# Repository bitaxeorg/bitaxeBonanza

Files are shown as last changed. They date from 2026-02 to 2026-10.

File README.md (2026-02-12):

bitaxeBonanza quad Intel BZM2 ASIC miner.

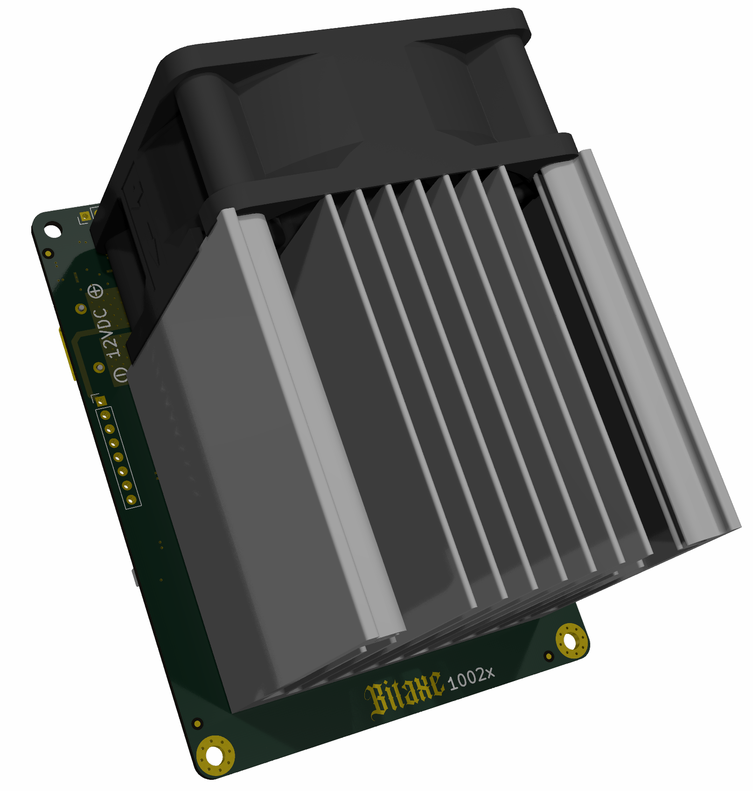
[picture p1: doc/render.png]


It is still an untested prototype! Don't build this expecting it to work out of the box. Do build it if you want to hack on some rad stuff.

- [Open Hardware License](LICENSE); Real Open Source.
	- [KiCAD](https://kicad.org) design files. 
- Four Intel BZM2 ASICs, powered in series.
	- Each BZM2 is [nominally](doc/specs.md) 0.7V with approx 350 GH/s @ 1.15 GHz hash frequency.
	- On chip digital temperature and voltage sensors
	- ntime rolling
- 11-13V XT30 input voltage
- TPS546D24S single-phase voltage regulator tuned for 2.8V output @ 20A
	- The voltage regulator backside power plane is exposed to hopefully thermally bond it with the main heatsink. 
- New fan control strategy (no more EMC2101)
- ESP32S3 for [esp-miner](https://github.com/bitaxeorg/esp-miner) support.
- 9-bit serial ASIC support via RP2040
    - Preliminary support with the [bitaxe-raw-pico](https://github.com/bitaxeorg/bitaxe-raw/tree/pico) firmware.
- Gerbers _not_ provided to discourage side hacks and AliEx slop. HMU if you need help generating gerbers with KiCad.

©️ [bitaxeorg](https://bitaxe.org)

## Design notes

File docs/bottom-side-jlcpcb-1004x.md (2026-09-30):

# Bottom-side JLCPCB parts — bitaxeBonanza 1004x

Catalog review: 2026-09-29. Source: saved `bitaxeBonanza.kicad_pcb` B.Cu position export joined to the schematic BOM, with the bitaxeProto-1103x BOM used for existing choices. Stock changes; recheck before placing an order.

- 209 bottom-side footprints: 180 schematic BOM parts in 56 original PARTNO groups, plus 29 test points, fiducials, mounting holes, and a net tie outside the assembly BOM.
- All 180 BOM positions have a selected JLCPCB/LCSC catalog code. These are candidate assembly selections, not an indication that all parts can be ordered today.
- 12 × D1–D12 use Preferred C7502722 (BAS516), with 33,674 available and the existing SOD-523 footprint. L1 now uses stocked Extended C3224581 (Bourns SRP1245A-1R2M).
- Equivalents are labeled separately from exact MPNs. Basic was selected where value, package, voltage, dielectric/tolerance or resistor rating agree. The 10 µF 25 V 0603 capacitor retains its ±10% exact part because the proto Basic choice is ±20%. Y1 uses the requested Proto Basic crystal, whose stability is ±20 ppm versus the original ±10 ppm.
- The saved schematic BOM has the selected `LCSC` code on all 180 bottom-side positions, including the manually updated reused sheets.

## Parts needing attention

| References | Selection | Finding |
| --- | --- | --- |
| D1–D12 | [C7502722](https://www.lcsc.com/product-detail/C7502722.html) | Preferred BAS516, 33,674 available; same SOD-523 footprint. It is rated 75 V versus the original 80 V. |
| L1 | [C3224581](https://jlcpcb.com/partdetail/BOURNS-SRP1245A1R2M/C3224581) | Bourns SRP1245A-1R2M, 65 available at the latest live check. The saved schematic and PCB use its land pattern; see verification below. |
| Q1 | [C7420339](https://www.lcsc.com/product-detail/C7420339.html) | Requested Proto generic BSS138 in SOT-23; this is an alternative to the original BSS138K-13 PARTNO. |
| Y2 | [C5137267](https://www.lcsc.com/product-detail/C5137267.html) | Exact 50 MHz oscillator, 10 available. This limits a multiple-board order. |
| D13 | [C24672](https://www.lcsc.com/product-detail/C24672.html) | Proto 3.3 V SOD-123 zener. Original DDZ9684-7 exact C165455 has 3 available. |
| Y1 | [C9002](https://www.lcsc.com/product-detail/C9002.html) | Requested Proto Basic 12 MHz, 20 pF, SMD3225-4P crystal; ±20 ppm stability versus the original ±10 ppm. |
| J1 | [C431092](https://www.lcsc.com/product-detail/C431092.html) | Proto XT30PW-M30.G.Y variant; confirm pin/tail geometry of the custom footprint. |

## D1–D12 replacement review

These diodes connect adjacent ASIC logic signals (TRIP, TX, RESET, and RX) with 1 kΩ resistors to the local 1.2 V rail or ground. The exported netlist indicates a low-voltage interface; the 75 V rating of BAS516 is ample for that use, although it is below the original diode's 80 V rating. The selected [BAS516 datasheet](https://wmsc.lcsc.com/wmsc/upload/file/pdf/v2/lcsc/2311171118_hongjiacheng-BAS516_C7502722.pdf) and [original DLLFSD01T datasheet](https://www.diodes.com/datasheet/download/DLLFSD01T.pdf) give:

| Property | Original DLLFSD01T-7 | Preferred BAS516 C7502722 | Preferred 1SS400 C7502721 |
| --- | --- | --- | --- |
| Package | SOD-523 | SOD-523 | SOD-523 |
| Reverse rating | 80 V | 75 V | 80 V |
| Forward voltage at 1 mA, max | 0.700 V | 0.715 V | Not specified |
| Capacitance at 0 V, max | 2.5 pF | 1.0 pF | 3.0 pF |
| Reverse recovery, max | 4 ns | 4 ns | 4 ns |
| Reverse leakage, max | 10 nA at 5 V; 0.2 µA at 80 V | 30 nA at 25 V; 1 µA at 75 V | 0.1 µA at 80 V |

The leakage figures use different test voltages and should not be compared as if measured under one condition. BAS516 has a specified low-current forward voltage and lower capacitance, which makes it the better fit for these logic shifters. [1SS400 C7502721](https://www.lcsc.com/product-detail/C7502721.html) is a same-footprint Preferred backup. The only Basic SOD-323 switching diode found, [1N4148WS C2128](https://www.lcsc.com/product-detail/C2128.html), needs a larger footprint and has a 1 µA leakage specification at 75 V. No Basic SOD-523 switching diode was listed in the catalog search.

The exact DLLFSD01T-7 is [C460049](https://www.lcsc.com/product-detail/C460049.html), with only 5 available for the 12 positions at the time of this review.

The existing `bitaxe:D_SOD-523` pads are 0.6 × 0.7 mm with 1.4 mm center spacing, within the BAS516 datasheet's suggested 0.55–0.65 × 0.65–0.75 mm pads and 1.37–1.47 mm spacing. No PCB footprint change is needed. Verify logic levels and edge timing on the first assembled board.

KiCad's saved schematic now exports BAS516 as the Value and PARTNO for D1–D12, with the new manufacturer and datasheet. The manually added `LCSC=C7502722` is present on all twelve exported BOM positions. The saved PCB footprint Values still show DLLFSD01T-7 because the PCB editor IPC endpoint did not accept Konnect's edit call.

## L1 replacement research

The saved [WEBENCH design report](../WebBench/WBDesign-1004x.pdf) is for 11–13 V input, 2.8 V at 20 A output, and 325 kHz switching. It calculates 5.738 A peak-to-peak inductor ripple and 22.869 A peak switch current. Current through L1 is therefore about 20.07 A RMS at that reported operating point. The report uses TPS546D24A, while the saved KiCad BOM names TPS546D24SRVFR for U2. The user has verified that TPS546D24S is a drop-in replacement for TPS546D24A; the WEBENCH values remain a reported operating point rather than a measurement of this board. The original Coilcraft XAL1060-122MEC is 1.2 µH, 2.5 mΩ typical DCR, 43 A saturation, and 17.9/26.3 A for a 20/40 °C rise [per Coilcraft](https://www.coilcraft.com/en-us/products/power/shielded-inductors/molded-inductor/xal/xal1060/xal1060-122/).

JLCPCB stock was checked live on 2026-09-29; all viable high-current choices found are **Extended** parts. The cataloged stock is an availability snapshot, not a reservation. The former L1 code C3911742 was out of stock; the selected C3224581 showed 65 in stock.

| Candidate | LCSC | µH | DCR typ/max | Irms | Isat | Body | Live stock | Assessment |
| --- | --- | ---: | ---: | ---: | ---: | --- | ---: | --- |
| [Bourns SRP1245A-1R2M](https://www.bourns.com/docs/product-datasheets/srp1245a.pdf) | [C3224581](https://jlcpcb.com/partdetail/BOURNS-SRP1245A1R2M/C3224581) | 1.2 | 2.5/3.0 mΩ | 28 A | 49 A | 13.5 × 12.5 × 4.8 mm | 65 | Selected and placed in KiCad. |
| Vishay IHLP5050FDER1R5M01, in WEBENCH list | [C1336173](https://www.lcsc.com/product-detail/C1336173.html) | 1.5 | 2.5 mΩ catalog value | 27 A | 45 A | 13.2 × 12.9 × 6.5 mm | 233 | Electrically plausible; WEBENCH accepts 1.5 µH. New footprint and height check needed. |
| [Tai-Tech TMPC1265HP-1R5MG-D](https://www.tai-tech.com.tw/tmpc1265hp) | [C357270](https://www.lcsc.com/product-detail/C357270.html) | 1.5 | 2.5/3.0 mΩ | 27 A | 45 A | 13.5 × 12.5 × 6.2 mm | 385 | More stocked 1.5 µH option; new footprint and compensation check needed. |
| Coilank APS1060M1R2F | [C49261245](https://www.lcsc.com/product-detail/C49261245.html) | 1.2 | 2.64 mΩ catalog value | 26.5 A | 45 A | 11.9 × 11 mm | 82 | Closest body size; manufacturer land pattern and current definitions still need verification. |

L1 now uses `bitaxe:SRP1245A-180M_BRN` in the schematic and on the bottom PCB. Although the footprint's library name contains `180M`, its two pads measure 3.0988 × 5.0038 mm at ±5.4506 mm, giving a 14.0 mm outer span and 7.80 mm inner gap. This closely follows the [Bourns series land pattern](https://www.bourns.com/docs/product-datasheets/srp1245a.pdf) of 14.2 mm outer span, 8.0 mm gap, and 5.0 mm pad height. The 1R2M and 180M use the same lead-frame package drawing. The schematic `PARTNO` was corrected to `SRP1245A-1R2M`; `LCSC=C3224581`, DK `118-SRP1245A-1R2MCT-ND`, and the pad nets (1 = `/Power/SW1`, 2 = `/VDD`) agree. The saved-board DRC reported no L1 violations or unconnected pads; it reported two unrelated warnings (J1 footprint/library mismatch and an F.Cu copper sliver). Bourns defines its 49 A saturation rating at a 20% inductance drop; Coilcraft defines the original 43 A at a 30% drop, so the headline ratings are not measured to the same threshold.

## Complete assembly selection

| References | Qty | Value | KiCad footprint | Design PARTNO | JLCPCB/LCSC | Catalog MPN | Class | Match | Source |
| --- | ---: | --- | --- | --- | --- | --- | --- | --- | --- |
| C2, C3, C4, C5, C6 | 5 | 22uF | `Capacitor_SMD:C_1206_3216Metric` | `TMK316BBJ226ML-T` | [C12891](https://www.lcsc.com/product-detail/C12891.html) | `CL31A226KAHNNNE` | basic | Equivalent | New catalog match |
| C7, C15, C19, C25, C26, C27, C28, C34, C38, C39, C68, C72 | 12 | 1uF | `Capacitor_SMD:C_0402_1005Metric` | `EMK105BJ105MV-F` | [C52923](https://www.lcsc.com/product-detail/C52923.html) | `CL05A105KA5NQNC` | basic | Equivalent | Bonanza existing |
| C9, C10 | 2 | 1uF | `Capacitor_SMD:C_0603_1608Metric` | `CL10B105KA8NNNC` | [C29936](https://www.lcsc.com/product-detail/C29936.html) | `CL10B105KA8NNNC` | extended | Exact MPN | New catalog match |
| C11 | 1 | 4.7uF | `Capacitor_SMD:C_0402_1005Metric` | `GRM155R61A475MEAAD` | [C23733](https://www.lcsc.com/product-detail/C23733.html) | `CL05A475MP5NRNC` | basic | Equivalent | Proto reused |
| C13 | 1 | 4.7nF | `Capacitor_SMD:C_0402_1005Metric` | `GRM155R71E472KA01D` | [C1538](https://www.lcsc.com/product-detail/C1538.html) | `0402B472K500NT` | basic | Equivalent | Proto reused |
| C14 | 1 | 2.2nF | `Capacitor_SMD:C_0402_1005Metric` | `GRM155R61H222KA01D` | [C1531](https://www.lcsc.com/product-detail/C1531.html) | `0402B222K500NT` | preferred | Equivalent | Proto reused |
| C16, C32, C36, C37, C40, C41, C42, C43, C44, C45, C46, C57, C58, C59, C77 | 15 | 0.1uF | `Capacitor_SMD:C_0402_1005Metric` | `KGM05AR71C104KH` | [C307331](https://www.lcsc.com/product-detail/C307331.html) | `CL05B104KB54PNC` | basic | Equivalent | Bonanza existing |
| C17 | 1 | 1000pF | `Capacitor_SMD:C_0805_2012Metric` | `CC0805KRX7R9BB102` | [C46653](https://www.lcsc.com/product-detail/C46653.html) | `CL21B102KBCNNNC` | basic | Equivalent | Proto reused |
| C18 | 1 | 100pF | `Capacitor_SMD:C_0402_1005Metric` | `CC0402JRNPO9BN101` | [C1546](https://www.lcsc.com/product-detail/C1546.html) | `0402CG101J500NT` | basic | Equivalent | Proto reused |
| C20 | 1 | 47uF | `Capacitor_SMD:C_1206_3216Metric` | `GRM31CR61A476ME15L` | [C96123](https://www.lcsc.com/product-detail/C96123.html) | `CL31A476MPHNNNE` | basic | Equivalent | New catalog match |
| C21, C22, C23, C24 | 4 | 100uF | `Capacitor_SMD:C_1206_3216Metric` | `CL31A107MQHNNNE` | [C15008](https://www.lcsc.com/product-detail/C15008.html) | `CL31A107MQHNNNE` | basic | Exact MPN | New catalog match |
| C33, C35 | 2 | 30pF | `Capacitor_SMD:C_0402_1005Metric` | `GRM1555C1H300JA01D` | [C1570](https://www.lcsc.com/product-detail/C1570.html) | `0402CG300J500NT` | preferred | Equivalent | Bonanza existing |
| C47, C76 | 2 | 10uF | `Capacitor_SMD:C_0603_1608Metric` | `GRM188R61E106KA73D` | [C344022](https://www.lcsc.com/product-detail/C344022.html) | `GRM188R61E106KA73D` | extended | Exact MPN | New catalog match |
| C48 | 1 | 12pF | `Capacitor_SMD:C_0402_1005Metric` | `CC0402JRNPO9BN120` | [C1547](https://www.lcsc.com/product-detail/C1547.html) | `0402CG120J500NT` | basic | Equivalent | Proto reused |
| C49, C50 | 2 | 10uF | `Capacitor_SMD:C_1210_3225Metric` | `CL32B106KBJNNNE` | [C138687](https://www.lcsc.com/product-detail/C138687.html) | `CL32B106KBJNNNE` | extended | Exact MPN | Bonanza existing |
| C51, C52, C55, C56, C67, C69, C70 | 7 | 0.1uF | `Capacitor_SMD:C_0402_1005Metric` | `CL05B104KB54PNC` | [C307331](https://www.lcsc.com/product-detail/C307331.html) | `CL05B104KB54PNC` | basic | Exact MPN | Bonanza existing |
| C53, C54 | 2 | 33nF | `Capacitor_SMD:C_0603_1608Metric` | `CL10B333KB8NNNC` | [C21117](https://www.lcsc.com/product-detail/C21117.html) | `CL10B333KB8NNNC` | basic | Exact MPN | Bonanza existing |
| C60, C61, C62, C63, C64 | 5 | 120pF | `Capacitor_SMD:C_0402_1005Metric` | `GCM1555C1H121FA16D` | [C126496](https://www.lcsc.com/product-detail/C126496.html) | `GCM1555C1H121FA16D` | extended | Exact MPN | New catalog match |
| C65, C66 | 2 | 22uF | `Capacitor_SMD:C_0805_2012Metric` | `CL21A226MAQNNNE` | [C45783](https://www.lcsc.com/product-detail/C45783.html) | `CL21A226MAQNNNE` | basic | Exact MPN | Bonanza existing |
| C83, C84, C85, C91, C92, C93, C99, C100, C101, C107, C108, C109, C115, C116, C117, C123, C124, C125, C131, C132, C133, C139, C140, C141 | 24 | 100uF | `Capacitor_SMD:C_0805_2012Metric` | `GRM21BR60G107ME11K` | [C7282454](https://www.lcsc.com/product-detail/C7282454.html) | `GRM21BR60G107ME11K` | extended | Exact MPN | New catalog match |
| C142, C143, C144 | 3 | 1000pF | `Capacitor_SMD:C_0402_1005Metric` | `GRM155R71H102KA01D` | [C1523](https://www.lcsc.com/product-detail/C1523.html) | `0402B102K500NT` | basic | Equivalent | New catalog match |
| D1, D2, D3, D4, D5, D6, D7, D8, D9, D10, D11, D12 | 12 | BAS516 | `bitaxe:D_SOD-523` | `BAS516` | [C7502722](https://www.lcsc.com/product-detail/C7502722.html) | `BAS516` | preferred | Exact MPN | New catalog match |
| D13 | 1 | 3.3V Zener | `Diode_SMD:D_SOD-123` | `DDZ9684-7` | [C24672](https://www.lcsc.com/product-detail/C24672.html) | `MMSZ4684T1G` | extended | Equivalent | Proto reused |
| FB1, FB2 | 2 | FerriteBead | `Inductor_SMD:L_1206_3216Metric` | `BLM31KN271SN1L` | [C703115](https://www.lcsc.com/product-detail/C703115.html) | `BLM31KN271SN1L` | extended | Exact MPN | Bonanza existing |
| J1 | 1 | XT30 | `bitaxe:XT30PW-M` | `XT30PW-M` | [C431092](https://www.lcsc.com/product-detail/C431092.html) | `XT30PW-M30.G.Y` | extended | Specified variant | Bonanza existing |
| J6 | 1 | USB_C_Receptacle_USB2.0 | `bitaxe:USB_C_Receptacle_GCT_USB4105-xx-A` | `USB4105-GF-A` | [C3020560](https://www.lcsc.com/product-detail/C3020560.html) | `USB4105-GF-A` | extended | Exact MPN | New catalog match |
| L1 | 1 | 1.2uH | `bitaxe:SRP1245A-180M_BRN` | `SRP1245A-1R2M` | [C3224581](https://jlcpcb.com/partdetail/BOURNS-SRP1245A1R2M/C3224581) | `SRP1245A-1R2M` | extended | Exact MPN | User selected |
| L2, L3 | 2 | 1.5uH | `bitaxe:IND-SMD_L2.0-W1.6` | `FTC201612S1R5MBCA` | [C5832350](https://www.lcsc.com/product-detail/C5832350.html) | `FTC201612S1R5MBCA` | extended | Exact MPN | Bonanza existing |
| Q1 | 1 | BSS138 | `Package_TO_SOT_SMD:SOT-23` | `BSS138K-13` | [C7420339](https://www.lcsc.com/product-detail/C7420339.html) | `BSS138` | preferred | Equivalent | Proto reused |
| R1, R4, R17, R35, R36, R37, R38, R39, R40, R41, R42, R43, R44, R45, R46, R47, R48, R49, R50, R51, R52 | 21 | 1k | `Resistor_SMD:R_0402_1005Metric` | `RC0402FR-071KL` | [C11702](https://www.lcsc.com/product-detail/C11702.html) | `0402WGF1001TCE` | basic | Equivalent | Proto reused |
| R2, R3, R9, R22, R34 | 5 | 10k | `Resistor_SMD:R_0402_1005Metric` | `RC0402JR-0710KL` | [C25744](https://www.lcsc.com/product-detail/C25744.html) | `0402WGF1002TCE` | basic | Equivalent | Proto reused |
| R5 | 1 | 10 | `Resistor_SMD:R_0402_1005Metric` | `RC0402FR-0710RL` | [C25077](https://www.lcsc.com/product-detail/C25077.html) | `0402WGF100JTCE` | basic | Equivalent | Proto reused |
| R6 | 1 | 1 | `Resistor_SMD:R_0805_2012Metric` | `ESR10EZPJ1R0` | [C253344](https://www.lcsc.com/product-detail/C253344.html) | `ESR10EZPJ1R0` | extended | Exact MPN | Proto reused |
| R7, R8 | 2 | 49.9 | `Resistor_SMD:R_0402_1005Metric` | `RC0402FR-0749R9L` | [C25120](https://www.lcsc.com/product-detail/C25120.html) | `0402WGF499JTCE` | basic | Equivalent | Proto reused |
| R14 | 1 | 10k | `Resistor_SMD:R_0402_1005Metric` | `RC0402FR-0710KL` | [C25744](https://www.lcsc.com/product-detail/C25744.html) | `0402WGF1002TCE` | basic | Equivalent | Bonanza existing |
| R15, R28 | 2 | 15k | `Resistor_SMD:R_0402_1005Metric` | `0402WGF1502TCE` | [C25756](https://www.lcsc.com/product-detail/C25756.html) | `0402WGF1502TCE` | basic | Exact MPN | Bonanza existing |
| R16 | 1 | 49.9k | `Resistor_SMD:R_0402_1005Metric` | `RC0402FR-0749K9L` | [C25897](https://www.lcsc.com/product-detail/C25897.html) | `0402WGF4992TCE` | preferred | Equivalent | New catalog match |
| R18, R19, R20, R21 | 4 | 4.7k | `Resistor_SMD:R_0402_1005Metric` | `RC0402FR-074K7L` | [C25900](https://www.lcsc.com/product-detail/C25900.html) | `0402WGF4701TCE` | basic | Equivalent | Proto reused |
| R23, R24 | 2 | 5.1k | `Resistor_SMD:R_0402_1005Metric` | `RMCF0402JT5K10` | [C25905](https://www.lcsc.com/product-detail/C25905.html) | `0402WGF5101TCE` | basic | Equivalent | Bonanza existing |
| R25 | 1 | 10k | `Resistor_SMD:R_0402_1005Metric` | `0402WGF1002TCE` | [C25744](https://www.lcsc.com/product-detail/C25744.html) | `0402WGF1002TCE` | basic | Exact MPN | Bonanza existing |
| R26 | 1 | 20k | `Resistor_SMD:R_0402_1005Metric` | `RC0402FR-0720KL` | [C25765](https://www.lcsc.com/product-detail/C25765.html) | `0402WGF2002TCE` | basic | Equivalent | New catalog match |
| R27 | 1 | 47k | `Resistor_SMD:R_0402_1005Metric` | `0402WGF4702TCE` | [C25792](https://www.lcsc.com/product-detail/C25792.html) | `0402WGF4702TCE` | basic | Exact MPN | Bonanza existing |
| R29 | 1 | 27k | `Resistor_SMD:R_0402_1005Metric` | `0402WGF2702TCE` | [C25771](https://www.lcsc.com/product-detail/C25771.html) | `0402WGF2702TCE` | preferred | Exact MPN | Bonanza existing |
| R30, R31, R32, R53 | 4 | 5.1k | `Resistor_SMD:R_0402_1005Metric` | `0402WGF5101TCE` | [C25905](https://www.lcsc.com/product-detail/C25905.html) | `0402WGF5101TCE` | basic | Exact MPN | Bonanza existing |
| R33 | 1 | 5.6k | `Resistor_SMD:R_0402_1005Metric` | `RC0402FR-075K6L` | [C25908](https://www.lcsc.com/product-detail/C25908.html) | `0402WGF5601TCE` | preferred | Equivalent | Proto reused |
| SW3, SW4 | 2 | SWITCH-SPST | `bitaxe:SW-SMD_TC-S3601-3.5-260G-F0.6` | `TC-S3601-3.5-260G-F0.6` | [C49101620](https://www.lcsc.com/product-detail/C49101620.html) | `TC-S3601-3.5-260G-F0.6` | extended | Exact MPN | Bonanza existing |
| U1, U3, U4, U6 | 4 | MCP1824T-1202E/OT | `bitaxe:SOT-23-5` | `MCP1824T-1202E/OT` | [C625461](https://www.lcsc.com/product-detail/C625461.html) | `MCP1824T-1202E/OT` | extended | Exact MPN | New catalog match |
| U2 | 1 | TPS546D24SRVFR | `bitaxe:LQFN40-CLIP` | `TPS546D24SRVFR` | [C20345977](https://www.lcsc.com/product-detail/C20345977.html) | `TPS546D24SRVFR` | extended | Exact MPN | Proto reused |
| U5 | 1 | W25Q16JVUXIQ TR | `bitaxe:USON-8_UX_2x3x0p6_WIN` | `W25Q16JVUXIQ TR` | [C2843335](https://www.lcsc.com/product-detail/C2843335.html) | `W25Q16JVUXIQ` | extended | Exact MPN | Bonanza existing |
| U8 | 1 | SN74AXC4T774 | `bitaxe:BQB0016A-MFG` | `SN74AXC4T774BQBR` | [C2862903](https://www.lcsc.com/product-detail/C2862903.html) | `SN74AXC4T774BQBR` | extended | Exact MPN | New catalog match |
| U9 | 1 | TPS22919DCKR | `bitaxe:DCK0006A_N` | `TPS22919DCKR` | [C2149796](https://www.lcsc.com/product-detail/C2149796.html) | `TPS22919DCKR` | extended | Exact MPN | Proto reused |
| U11 | 1 | RP2040 | `bitaxe:RP2040-QFN-56-1EP_7x7mm_P0.4mm_EP3.2x3.2mm` | `SC0914(13)` | [C2040](https://www.lcsc.com/product-detail/C2040.html) | `RP2040` | extended | Same device | Bonanza existing |
| U12 | 1 | ESP32-S3-WROOM-1 | `bitaxe:ESP32-S3-WROOM-1` | `ESP32-S3-WROOM-1-N16R8` | [C2913202](https://www.lcsc.com/product-detail/C2913202.html) | `ESP32-S3-WROOM-1-N16R8` | extended | Exact MPN | Proto reused |
| U13, U14 | 2 | TPS62933DRLR | `bitaxe:SOT-583-8_L2.1-W1.2-P0.50-LS1.6-BR` | `TPS62933DRLR` | [C3200405](https://www.lcsc.com/product-detail/C3200405.html) | `TPS62933DRLR` | extended | Exact MPN | Bonanza existing |
| Y1 | 1 | 12MHz | `bitaxe:XTAL_ECS-120-20-33-CKM-TR3` | `ECS-120-20-33-CKM-TR3` | [C9002](https://www.lcsc.com/product-detail/C9002.html) | `X322512MSB4SI` | basic | Equivalent | Proto reused |
| Y2 | 1 | 50MHz | `bitaxe:OSC_ECS-3225MV-500-CN-TR` | `SX3M50.000E20F30THN` | [C5137267](https://www.lcsc.com/product-detail/C5137267.html) | `SX3M50.000E20F30THN` | extended | Exact MPN | Bonanza existing |

The [per-reference CSV](bottom-side-jlcpcb-1004x.csv) includes all 180 bottom-side BOM positions, current saved schematic LCSC fields, catalog stock seen during the review, and any part-specific notes. Stock counts represent catalog snapshots and are not a reservation. The 29 excluded footprint references are: FID3, FID4, H5, H6, H7, H8, NT1, TP1, TP2, TP3, TP4, TP5, TP7, TP8, TP10, TP16, TP18, TP19, TP23, TP24, TP25, TP26, TP27, TP58, TP59, TP60, TP61, TP62, TP63.

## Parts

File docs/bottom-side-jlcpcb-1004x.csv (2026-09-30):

reference | value | footprint | design_partno | schematic_lcsc | selected_lcsc | jlc_mpn | jlc_package | library_type | match | provenance | catalog_stock | note
C2 | 22uF | Capacitor_SMD:C_1206_3216Metric | TMK316BBJ226ML-T | C12891 | C12891 | CL31A226KAHNNNE | 1206 | basic | Equivalent | New catalog match | 621280
C3 | 22uF | Capacitor_SMD:C_1206_3216Metric | TMK316BBJ226ML-T | C12891 | C12891 | CL31A226KAHNNNE | 1206 | basic | Equivalent | New catalog match | 621280
C4 | 22uF | Capacitor_SMD:C_1206_3216Metric | TMK316BBJ226ML-T | C12891 | C12891 | CL31A226KAHNNNE | 1206 | basic | Equivalent | New catalog match | 621280
C5 | 22uF | Capacitor_SMD:C_1206_3216Metric | TMK316BBJ226ML-T | C12891 | C12891 | CL31A226KAHNNNE | 1206 | basic | Equivalent | New catalog match | 621280
C6 | 22uF | Capacitor_SMD:C_1206_3216Metric | TMK316BBJ226ML-T | C12891 | C12891 | CL31A226KAHNNNE | 1206 | basic | Equivalent | New catalog match | 621280
C7 | 1uF | Capacitor_SMD:C_0402_1005Metric | EMK105BJ105MV-F | C52923 | C52923 | CL05A105KA5NQNC | 0402 | basic | Equivalent | Bonanza existing | 5980560
C9 | 1uF | Capacitor_SMD:C_0603_1608Metric | CL10B105KA8NNNC | C29936 | C29936 | CL10B105KA8NNNC | 0603 | extended | Exact MPN | New catalog match | 375039
C10 | 1uF | Capacitor_SMD:C_0603_1608Metric | CL10B105KA8NNNC | C29936 | C29936 | CL10B105KA8NNNC | 0603 | extended | Exact MPN | New catalog match | 375039
C11 | 4.7uF | Capacitor_SMD:C_0402_1005Metric | GRM155R61A475MEAAD | C23733 | C23733 | CL05A475MP5NRNC | 0402 | basic | Equivalent | Proto reused | 2451180
C13 | 4.7nF | Capacitor_SMD:C_0402_1005Metric | GRM155R71E472KA01D | C1538 | C1538 | 0402B472K500NT | 0402 | basic | Equivalent | Proto reused | 1372556
C14 | 2.2nF | Capacitor_SMD:C_0402_1005Metric | GRM155R61H222KA01D | C1531 | C1531 | 0402B222K500NT | 0402 | preferred | Equivalent | Proto reused | 536614
C15 | 1uF | Capacitor_SMD:C_0402_1005Metric | EMK105BJ105MV-F | C52923 | C52923 | CL05A105KA5NQNC | 0402 | basic | Equivalent | Bonanza existing | 5980560
C16 | 0.1uF | Capacitor_SMD:C_0402_1005Metric | KGM05AR71C104KH | C307331 | C307331 | CL05B104KB54PNC | 0402 | basic | Equivalent | Bonanza existing | 13110609
C17 | 1000pF | Capacitor_SMD:C_0805_2012Metric | CC0805KRX7R9BB102 | C46653 | C46653 | CL21B102KBCNNNC | 0805 | basic | Equivalent | Proto reused | 1569643
C18 | 100pF | Capacitor_SMD:C_0402_1005Metric | CC0402JRNPO9BN101 | C1546 | C1546 | 0402CG101J500NT | 0402 | basic | Equivalent | Proto reused | 3373974
C19 | 1uF | Capacitor_SMD:C_0402_1005Metric | EMK105BJ105MV-F | C52923 | C52923 | CL05A105KA5NQNC | 0402 | basic | Equivalent | Bonanza existing | 5980560
C20 | 47uF | Capacitor_SMD:C_1206_3216Metric | GRM31CR61A476ME15L | C96123 | C96123 | CL31A476MPHNNNE | 1206 | basic | Equivalent | New catalog match | 315260
C21 | 100uF | Capacitor_SMD:C_1206_3216Metric | CL31A107MQHNNNE | C15008 | C15008 | CL31A107MQHNNNE | 1206 | basic | Exact MPN | New catalog match | 1989403
C22 | 100uF | Capacitor_SMD:C_1206_3216Metric | CL31A107MQHNNNE | C15008 | C15008 | CL31A107MQHNNNE | 1206 | basic | Exact MPN | New catalog match | 1989403
C23 | 100uF | Capacitor_SMD:C_1206_3216Metric | CL31A107MQHNNNE | C15008 | C15008 | CL31A107MQHNNNE | 1206 | basic | Exact MPN | New catalog match | 1989403
C24 | 100uF | Capacitor_SMD:C_1206_3216Metric | CL31A107MQHNNNE | C15008 | C15008 | CL31A107MQHNNNE | 1206 | basic | Exact MPN | New catalog match | 1989403
C25 | 1uF | Capacitor_SMD:C_0402_1005Metric | EMK105BJ105MV-F | C52923 | C52923 | CL05A105KA5NQNC | 0402 | basic | Equivalent | Bonanza existing | 5980560
C26 | 1uF | Capacitor_SMD:C_0402_1005Metric | EMK105BJ105MV-F | C52923 | C52923 | CL05A105KA5NQNC | 0402 | basic | Equivalent | Bonanza existing | 5980560
C27 | 1uF | Capacitor_SMD:C_0402_1005Metric | EMK105BJ105MV-F | C52923 | C52923 | CL05A105KA5NQNC | 0402 | basic | Equivalent | Bonanza existing | 5980560
C28 | 1uF | Capacitor_SMD:C_0402_1005Metric | EMK105BJ105MV-F | C52923 | C52923 | CL05A105KA5NQNC | 0402 | basic | Equivalent | Bonanza existing | 5980560
C32 | 0.1uF | Capacitor_SMD:C_0402_1005Metric | KGM05AR71C104KH | C307331 | C307331 | CL05B104KB54PNC | 0402 | basic | Equivalent | Bonanza existing | 13110609
C33 | 30pF | Capacitor_SMD:C_0402_1005Metric | GRM1555C1H300JA01D | C1570 | C1570 | 0402CG300J500NT | 0402 | preferred | Equivalent | Bonanza existing | 197761
C34 | 1uF | Capacitor_SMD:C_0402_1005Metric | EMK105BJ105MV-F | C52923 | C52923 | CL05A105KA5NQNC | 0402 | basic | Equivalent | Bonanza existing | 5980560
C35 | 30pF | Capacitor_SMD:C_0402_1005Metric | GRM1555C1H300JA01D | C1570 | C1570 | 0402CG300J500NT | 0402 | preferred | Equivalent | Bonanza existing | 197761
C36 | 0.1uF | Capacitor_SMD:C_0402_1005Metric | KGM05AR71C104KH | C307331 | C307331 | CL05B104KB54PNC | 0402 | basic | Equivalent | Bonanza existing | 13110609
C37 | 0.1uF | Capacitor_SMD:C_0402_1005Metric | KGM05AR71C104KH | C307331 | C307331 | CL05B104KB54PNC | 0402 | basic | Equivalent | Bonanza existing | 13110609
C38 | 1uF | Capacitor_SMD:C_0402_1005Metric | EMK105BJ105MV-F | C52923 | C52923 | CL05A105KA5NQNC | 0402 | basic | Equivalent | Bonanza existing | 5980560
C39 | 1uF | Capacitor_SMD:C_0402_1005Metric | EMK105BJ105MV-F | C52923 | C52923 | CL05A105KA5NQNC | 0402 | basic | Equivalent | Bonanza existing | 5980560
C40 | 0.1uF | Capacitor_SMD:C_0402_1005Metric | KGM05AR71C104KH | C307331 | C307331 | CL05B104KB54PNC | 0402 | basic | Equivalent | Bonanza existing | 13110609
C41 | 0.1uF | Capacitor_SMD:C_0402_1005Metric | KGM05AR71C104KH | C307331 | C307331 | CL05B104KB54PNC | 0402 | basic | Equivalent | Bonanza existing | 13110609
C42 | 0.1uF | Capacitor_SMD:C_0402_1005Metric | KGM05AR71C104KH | C307331 | C307331 | CL05B104KB54PNC | 0402 | basic | Equivalent | Bonanza existing | 13110609
C43 | 0.1uF | Capacitor_SMD:C_0402_1005Metric | KGM05AR71C104KH | C307331 | C307331 | CL05B104KB54PNC | 0402 | basic | Equivalent | Bonanza existing | 13110609
C44 | 0.1uF | Capacitor_SMD:C_0402_1005Metric | KGM05AR71C104KH | C307331 | C307331 | CL05B104KB54PNC | 0402 | basic | Equivalent | Bonanza existing | 13110609
C45 | 0.1uF | Capacitor_SMD:C_0402_1005Metric | KGM05AR71C104KH | C307331 | C307331 | CL05B104KB54PNC | 0402 | basic | Equivalent | Bonanza existing | 13110609
C46 | 0.1uF | Capacitor_SMD:C_0402_1005Metric | KGM05AR71C104KH | C307331 | C307331 | CL05B104KB54PNC | 0402 | basic | Equivalent | Bonanza existing | 13110609
C47 | 10uF | Capacitor_SMD:C_0603_1608Metric | GRM188R61E106KA73D | C344022 | C344022 | GRM188R61E106KA73D | 0603 | extended | Exact MPN | New catalog match | 301907 | Exact 10 uF 25 V X5R ±10%; proto Basic C96446 is ±20%, so not selected.
C48 | 12pF | Capacitor_SMD:C_0402_1005Metric | CC0402JRNPO9BN120 | C1547 | C1547 | 0402CG120J500NT | 0402 | basic | Equivalent | Proto reused | 2012795
C49 | 10uF | Capacitor_SMD:C_1210_3225Metric | CL32B106KBJNNNE | C138687 | C138687 | CL32B106KBJNNNE | 1210 | extended | Exact MPN | Bonanza existing | 33868
C50 | 10uF | Capacitor_SMD:C_1210_3225Metric | CL32B106KBJNNNE | C138687 | C138687 | CL32B106KBJNNNE | 1210 | extended | Exact MPN | Bonanza existing | 33868
C51 | 0.1uF | Capacitor_SMD:C_0402_1005Metric | CL05B104KB54PNC | C307331 | C307331 | CL05B104KB54PNC | 0402 | basic | Exact MPN | Bonanza existing | 13110609
C52 | 0.1uF | Capacitor_SMD:C_0402_1005Metric | CL05B104KB54PNC | C307331 | C307331 | CL05B104KB54PNC | 0402 | basic | Exact MPN | Bonanza existing | 13110609
C53 | 33nF | Capacitor_SMD:C_0603_1608Metric | CL10B333KB8NNNC | C21117 | C21117 | CL10B333KB8NNNC | 0603 | basic | Exact MPN | Bonanza existing | 1064074
C54 | 33nF | Capacitor_SMD:C_0603_1608Metric | CL10B333KB8NNNC | C21117 | C21117 | CL10B333KB8NNNC | 0603 | basic | Exact MPN | Bonanza existing | 1064074
C55 | 0.1uF | Capacitor_SMD:C_0402_1005Metric | CL05B104KB54PNC | C307331 | C307331 | CL05B104KB54PNC | 0402 | basic | Exact MPN | Bonanza existing | 13110609
C56 | 0.1uF | Capacitor_SMD:C_0402_1005Metric | CL05B104KB54PNC | C307331 | C307331 | CL05B104KB54PNC | 0402 | basic | Exact MPN | Bonanza existing | 13110609
C57 | 0.1uF | Capacitor_SMD:C_0402_1005Metric | KGM05AR71C104KH | C307331 | C307331 | CL05B104KB54PNC | 0402 | basic | Equivalent | Bonanza existing | 13110609
C58 | 0.1uF | Capacitor_SMD:C_0402_1005Metric | KGM05AR71C104KH | C307331 | C307331 | CL05B104KB54PNC | 0402 | basic | Equivalent | Bonanza existing | 13110609
C59 | 0.1uF | Capacitor_SMD:C_0402_1005Metric | KGM05AR71C104KH | C307331 | C307331 | CL05B104KB54PNC | 0402 | basic | Equivalent | Bonanza existing | 13110609
C60 | 120pF | Capacitor_SMD:C_0402_1005Metric | GCM1555C1H121FA16D | C126496 | C126496 | GCM1555C1H121FA16D | 0402 | extended | Exact MPN | New catalog match | 20947 | Retains the original 120 pF C0G ±1% tolerance.
C61 | 120pF | Capacitor_SMD:C_0402_1005Metric | GCM1555C1H121FA16D | C126496 | C126496 | GCM1555C1H121FA16D | 0402 | extended | Exact MPN | New catalog match | 20947 | Retains the original 120 pF C0G ±1% tolerance.
C62 | 120pF | Capacitor_SMD:C_0402_1005Metric | GCM1555C1H121FA16D | C126496 | C126496 | GCM1555C1H121FA16D | 0402 | extended | Exact MPN | New catalog match | 20947 | Retains the original 120 pF C0G ±1% tolerance.
C63 | 120pF | Capacitor_SMD:C_0402_1005Metric | GCM1555C1H121FA16D | C126496 | C126496 | GCM1555C1H121FA16D | 0402 | extended | Exact MPN | New catalog match | 20947 | Retains the original 120 pF C0G ±1% tolerance.
C64 | 120pF | Capacitor_SMD:C_0402_1005Metric | GCM1555C1H121FA16D | C126496 | C126496 | GCM1555C1H121FA16D | 0402 | extended | Exact MPN | New catalog match | 20947 | Retains the original 120 pF C0G ±1% tolerance.
C65 | 22uF | Capacitor_SMD:C_0805_2012Metric | CL21A226MAQNNNE | C45783 | C45783 | CL21A226MAQNNNE | 0805 | basic | Exact MPN | Bonanza existing | 4060803
C66 | 22uF | Capacitor_SMD:C_0805_2012Metric | CL21A226MAQNNNE | C45783 | C45783 | CL21A226MAQNNNE | 0805 | basic | Exact MPN | Bonanza existing | 4060803
C67 | 0.1uF | Capacitor_SMD:C_0402_1005Metric | CL05B104KB54PNC | C307331 | C307331 | CL05B104KB54PNC | 0402 | basic | Exact MPN | Bonanza existing | 13110609
C68 | 1uF | Capacitor_SMD:C_0402_1005Metric | EMK105BJ105MV-F | C52923 | C52923 | CL05A105KA5NQNC | 0402 | basic | Equivalent | Bonanza existing | 5980560
C69 | 0.1uF | Capacitor_SMD:C_0402_1005Metric | CL05B104KB54PNC | C307331 | C307331 | CL05B104KB54PNC | 0402 | basic | Exact MPN | Bonanza existing | 13110609
C70 | 0.1uF | Capacitor_SMD:C_0402_1005Metric | CL05B104KB54PNC | C307331 | C307331 | CL05B104KB54PNC | 0402 | basic | Exact MPN | Bonanza existing | 13110609
C72 | 1uF | Capacitor_SMD:C_0402_1005Metric | EMK105BJ105MV-F | C52923 | C52923 | CL05A105KA5NQNC | 0402 | basic | Equivalent | Bonanza existing | 5980560
C76 | 10uF | Capacitor_SMD:C_0603_1608Metric | GRM188R61E106KA73D | C344022 | C344022 | GRM188R61E106KA73D | 0603 | extended | Exact MPN | New catalog match | 301907 | Exact 10 uF 25 V X5R ±10%; proto Basic C96446 is ±20%, so not selected.
C77 | 0.1uF | Capacitor_SMD:C_0402_1005Metric | KGM05AR71C104KH | C307331 | C307331 | CL05B104KB54PNC | 0402 | basic | Equivalent | Bonanza existing | 13110609
C83 | 100uF | Capacitor_SMD:C_0805_2012Metric | GRM21BR60G107ME11K | C7282454 | C7282454 | GRM21BR60G107ME11K | 0805 | extended | Exact MPN | New catalog match | 1391 | Exact 100 uF 4 V 0805; do not substitute a 1206 or smaller capacitance.
C84 | 100uF | Capacitor_SMD:C_0805_2012Metric | GRM21BR60G107ME11K | C7282454 | C7282454 | GRM21BR60G107ME11K | 0805 | extended | Exact MPN | New catalog match | 1391 | Exact 100 uF 4 V 0805; do not substitute a 1206 or smaller capacitance.
C85 | 100uF | Capacitor_SMD:C_0805_2012Metric | GRM21BR60G107ME11K | C7282454 | C7282454 | GRM21BR60G107ME11K | 0805 | extended | Exact MPN | New catalog match | 1391 | Exact 100 uF 4 V 0805; do not substitute a 1206 or smaller capacitance.
C91 | 100uF | Capacitor_SMD:C_0805_2012Metric | GRM21BR60G107ME11K | C7282454 | C7282454 | GRM21BR60G107ME11K | 0805 | extended | Exact MPN | New catalog match | 1391 | Exact 100 uF 4 V 0805; do not substitute a 1206 or smaller capacitance.
C92 | 100uF | Capacitor_SMD:C_0805_2012Metric | GRM21BR60G107ME11K | C7282454 | C7282454 | GRM21BR60G107ME11K | 0805 | extended | Exact MPN | New catalog match | 1391 | Exact 100 uF 4 V 0805; do not substitute a 1206 or smaller capacitance.
C93 | 100uF | Capacitor_SMD:C_0805_2012Metric | GRM21BR60G107ME11K | C7282454 | C7282454 | GRM21BR60G107ME11K | 0805 | extended | Exact MPN | New catalog match | 1391 | Exact 100 uF 4 V 0805; do not substitute a 1206 or smaller capacitance.
C99 | 100uF | Capacitor_SMD:C_0805_2012Metric | GRM21BR60G107ME11K | C7282454 | C7282454 | GRM21BR60G107ME11K | 0805 | extended | Exact MPN | New catalog match | 1391 | Exact 100 uF 4 V 0805; do not substitute a 1206 or smaller capacitance.
C100 | 100uF | Capacitor_SMD:C_0805_2012Metric | GRM21BR60G107ME11K | C7282454 | C7282454 | GRM21BR60G107ME11K | 0805 | extended | Exact MPN | New catalog match | 1391 | Exact 100 uF 4 V 0805; do not substitute a 1206 or smaller capacitance.
C101 | 100uF | Capacitor_SMD:C_0805_2012Metric | GRM21BR60G107ME11K | C7282454 | C7282454 | GRM21BR60G107ME11K | 0805 | extended | Exact MPN | New catalog match | 1391 | Exact 100 uF 4 V 0805; do not substitute a 1206 or smaller capacitance.
C107 | 100uF | Capacitor_SMD:C_0805_2012Metric | GRM21BR60G107ME11K | C7282454 | C7282454 | GRM21BR60G107ME11K | 0805 | extended | Exact MPN | New catalog match | 1391 | Exact 100 uF 4 V 0805; do not substitute a 1206 or smaller capacitance.
C108 | 100uF | Capacitor_SMD:C_0805_2012Metric | GRM21BR60G107ME11K | C7282454 | C7282454 | GRM21BR60G107ME11K | 0805 | extended | Exact MPN | New catalog match | 1391 | Exact 100 uF 4 V 0805; do not substitute a 1206 or smaller capacitance.
C109 | 100uF | Capacitor_SMD:C_0805_2012Metric | GRM21BR60G107ME11K | C7282454 | C7282454 | GRM21BR60G107ME11K | 0805 | extended | Exact MPN | New catalog match | 1391 | Exact 100 uF 4 V 0805; do not substitute a 1206 or smaller capacitance.
C115 | 100uF | Capacitor_SMD:C_0805_2012Metric | GRM21BR60G107ME11K | C7282454 | C7282454 | GRM21BR60G107ME11K | 0805 | extended | Exact MPN | New catalog match | 1391 | Exact 100 uF 4 V 0805; do not substitute a 1206 or smaller capacitance.
C116 | 100uF | Capacitor_SMD:C_0805_2012Metric | GRM21BR60G107ME11K | C7282454 | C7282454 | GRM21BR60G107ME11K | 0805 | extended | Exact MPN | New catalog match | 1391 | Exact 100 uF 4 V 0805; do not substitute a 1206 or smaller capacitance.
C117 | 100uF | Capacitor_SMD:C_0805_2012Metric | GRM21BR60G107ME11K | C7282454 | C7282454 | GRM21BR60G107ME11K | 0805 | extended | Exact MPN | New catalog match | 1391 | Exact 100 uF 4 V 0805; do not substitute a 1206 or smaller capacitance.
C123 | 100uF | Capacitor_SMD:C_0805_2012Metric | GRM21BR60G107ME11K | C7282454 | C7282454 | GRM21BR60G107ME11K | 0805 | extended | Exact MPN | New catalog match | 1391 | Exact 100 uF 4 V 0805; do not substitute a 1206 or smaller capacitance.
C124 | 100uF | Capacitor_SMD:C_0805_2012Metric | GRM21BR60G107ME11K | C7282454 | C7282454 | GRM21BR60G107ME11K | 0805 | extended | Exact MPN | New catalog match | 1391 | Exact 100 uF 4 V 0805; do not substitute a 1206 or smaller capacitance.
C125 | 100uF | Capacitor_SMD:C_0805_2012Metric | GRM21BR60G107ME11K | C7282454 | C7282454 | GRM21BR60G107ME11K | 0805 | extended | Exact MPN | New catalog match | 1391 | Exact 100 uF 4 V 0805; do not substitute a 1206 or smaller capacitance.
C131 | 100uF | Capacitor_SMD:C_0805_2012Metric | GRM21BR60G107ME11K | C7282454 | C7282454 | GRM21BR60G107ME11K | 0805 | extended | Exact MPN | New catalog match | 1391 | Exact 100 uF 4 V 0805; do not substitute a 1206 or smaller capacitance.
C132 | 100uF | Capacitor_SMD:C_0805_2012Metric | GRM21BR60G107ME11K | C7282454 | C7282454 | GRM21BR60G107ME11K | 0805 | extended | Exact MPN | New catalog match | 1391 | Exact 100 uF 4 V 0805; do not substitute a 1206 or smaller capacitance.
C133 | 100uF | Capacitor_SMD:C_0805_2012Metric | GRM21BR60G107ME11K | C7282454 | C7282454 | GRM21BR60G107ME11K | 0805 | extended | Exact MPN | New catalog match | 1391 | Exact 100 uF 4 V 0805; do not substitute a 1206 or smaller capacitance.
C139 | 100uF | Capacitor_SMD:C_0805_2012Metric | GRM21BR60G107ME11K | C7282454 | C7282454 | GRM21BR60G107ME11K | 0805 | extended | Exact MPN | New catalog match | 1391 | Exact 100 uF 4 V 0805; do not substitute a 1206 or smaller capacitance.
C140 | 100uF | Capacitor_SMD:C_0805_2012Metric | GRM21BR60G107ME11K | C7282454 | C7282454 | GRM21BR60G107ME11K | 0805 | extended | Exact MPN | New catalog match | 1391 | Exact 100 uF 4 V 0805; do not substitute a 1206 or smaller capacitance.
C141 | 100uF | Capacitor_SMD:C_0805_2012Metric | GRM21BR60G107ME11K | C7282454 | C7282454 | GRM21BR60G107ME11K | 0805 | extended | Exact MPN | New catalog match | 1391 | Exact 100 uF 4 V 0805; do not substitute a 1206 or smaller capacitance.
C142 | 1000pF | Capacitor_SMD:C_0402_1005Metric | GRM155R71H102KA01D | C1523 | C1523 | 0402B102K500NT | 0402 | basic | Equivalent | New catalog match | 3558149
C143 | 1000pF | Capacitor_SMD:C_0402_1005Metric | GRM155R71H102KA01D | C1523 | C1523 | 0402B102K500NT | 0402 | basic | Equivalent | New catalog match | 3558149
C144 | 1000pF | Capacitor_SMD:C_0402_1005Metric | GRM155R71H102KA01D | C1523 | C1523 | 0402B102K500NT | 0402 | basic | Equivalent | New catalog match | 3558149
D1 | BAS516 | bitaxe:D_SOD-523 | BAS516 | C7502722 | C7502722 | BAS516 | SOD-523 | preferred | Exact MPN | New catalog match | 33674 | Saved schematic Value/PARTNO BAS516 and manually added LCSC=C7502722 verified in exported BOM; same SOD-523 footprint.
D2 | BAS516 | bitaxe:D_SOD-523 | BAS516 | C7502722 | C7502722 | BAS516 | SOD-523 | preferred | Exact MPN | New catalog match | 33674 | Saved schematic Value/PARTNO BAS516 and manually added LCSC=C7502722 verified in exported BOM; same SOD-523 footprint.
D3 | BAS516 | bitaxe:D_SOD-523 | BAS516 | C7502722 | C7502722 | BAS516 | SOD-523 | preferred | Exact MPN | New catalog match | 33674 | Saved schematic Value/PARTNO BAS516 and manually added LCSC=C7502722 verified in exported BOM; same SOD-523 footprint.
D4 | BAS516 | bitaxe:D_SOD-523 | BAS516 | C7502722 | C7502722 | BAS516 | SOD-523 | preferred | Exact MPN | New catalog match | 33674 | Saved schematic Value/PARTNO BAS516 and manually added LCSC=C7502722 verified in exported BOM; same SOD-523 footprint.
D5 | BAS516 | bitaxe:D_SOD-523 | BAS516 | C7502722 | C7502722 | BAS516 | SOD-523 | preferred | Exact MPN | New catalog match | 33674 | Saved schematic Value/PARTNO BAS516 and manually added LCSC=C7502722 verified in exported BOM; same SOD-523 footprint.
D6 | BAS516 | bitaxe:D_SOD-523 | BAS516 | C7502722 | C7502722 | BAS516 | SOD-523 | preferred | Exact MPN | New catalog match | 33674 | Saved schematic Value/PARTNO BAS516 and manually added LCSC=C7502722 verified in exported BOM; same SOD-523 footprint.
D7 | BAS516 | bitaxe:D_SOD-523 | BAS516 | C7502722 | C7502722 | BAS516 | SOD-523 | preferred | Exact MPN | New catalog match | 33674 | Saved schematic Value/PARTNO BAS516 and manually added LCSC=C7502722 verified in exported BOM; same SOD-523 footprint.
D8 | BAS516 | bitaxe:D_SOD-523 | BAS516 | C7502722 | C7502722 | BAS516 | SOD-523 | preferred | Exact MPN | New catalog match | 33674 | Saved schematic Value/PARTNO BAS516 and manually added LCSC=C7502722 verified in exported BOM; same SOD-523 footprint.
D9 | BAS516 | bitaxe:D_SOD-523 | BAS516 | C7502722 | C7502722 | BAS516 | SOD-523 | preferred | Exact MPN | New catalog match | 33674 | Saved schematic Value/PARTNO BAS516 and manually added LCSC=C7502722 verified in exported BOM; same SOD-523 footprint.
D10 | BAS516 | bitaxe:D_SOD-523 | BAS516 | C7502722 | C7502722 | BAS516 | SOD-523 | preferred | Exact MPN | New catalog match | 33674 | Saved schematic Value/PARTNO BAS516 and manually added LCSC=C7502722 verified in exported BOM; same SOD-523 footprint.
D11 | BAS516 | bitaxe:D_SOD-523 | BAS516 | C7502722 | C7502722 | BAS516 | SOD-523 | preferred | Exact MPN | New catalog match | 33674 | Saved schematic Value/PARTNO BAS516 and manually added LCSC=C7502722 verified in exported BOM; same SOD-523 footprint.
D12 | BAS516 | bitaxe:D_SOD-523 | BAS516 | C7502722 | C7502722 | BAS516 | SOD-523 | preferred | Exact MPN | New catalog match | 33674 | Saved schematic Value/PARTNO BAS516 and manually added LCSC=C7502722 verified in exported BOM; same SOD-523 footprint.
D13 | 3.3V Zener | Diode_SMD:D_SOD-123 | DDZ9684-7 | C24672 | C24672 | MMSZ4684T1G | SOD-123 | extended | Equivalent | Proto reused | 11919 | Proto 3.3 V SOD-123 alternative; original DDZ9684-7 exact code C165455 has only 3 available.
FB1 | FerriteBead | Inductor_SMD:L_1206_3216Metric | BLM31KN271SN1L | C703115 | C703115 | BLM31KN271SN1L | 1206 | extended | Exact MPN | Bonanza existing | 176
FB2 | FerriteBead | Inductor_SMD:L_1206_3216Metric | BLM31KN271SN1L | C703115 | C703115 | BLM31KN271SN1L | 1206 | extended | Exact MPN | Bonanza existing | 176
J1 | XT30 | bitaxe:XT30PW-M | XT30PW-M | C431092 | C431092 | XT30PW-M30.G.Y | - | extended | Specified variant | Bonanza existing | 31541 | Specific XT30PW-M30.G.Y variant inherited from proto; verify tail length against custom footprint.
J6 | USB_C_Receptacle_USB2.0 | bitaxe:USB_C_Receptacle_GCT_USB4105-xx-A | USB4105-GF-A | C3020560 | C3020560 | USB4105-GF-A | SMD | extended | Exact MPN | New catalog match | 1031
L1 | 1.2uH | bitaxe:SRP1245A-180M_BRN | SRP1245A-1R2M | C3224581 | C3224581 | SRP1245A-1R2M | SMD,13.5x12.5mm | extended | Exact MPN | User selected | 65 | User selected Bourns; saved PCB and schematic use series land pattern named SRP1245A-180M_BRN. PARTNO corrected to SRP1245A-1R2M. Live JLC stock 65 on 2026-09-29; saved-board DRC found no L1 violations.
L2 | 1.5uH | bitaxe:IND-SMD_L2.0-W1.6 | FTC201612S1R5MBCA | C5832350 | C5832350 | FTC201612S1R5MBCA | 0806 | extended | Exact MPN | Bonanza existing | 1225
L3 | 1.5uH | bitaxe:IND-SMD_L2.0-W1.6 | FTC201612S1R5MBCA | C5832350 | C5832350 | FTC201612S1R5MBCA | 0806 | extended | Exact MPN | Bonanza existing | 1225
Q1 | BSS138 | Package_TO_SOT_SMD:SOT-23 | BSS138K-13 | C7420339 | C7420339 | BSS138 | SOT-23 | preferred | Equivalent | Proto reused |  | Requested Proto generic BSS138; replaces original protected-gate BSS138K-13 selection. Schematic PARTNO still identifies the original design part.
R1 | 1k | Resistor_SMD:R_0402_1005Metric | RC0402FR-071KL | C11702 | C11702 | 0402WGF1001TCE | 0402 | basic | Equivalent | Proto reused | 8054795
R2 | 10k | Resistor_SMD:R_0402_1005Metric | RC0402JR-0710KL | C25744 | C25744 | 0402WGF1002TCE | 0402 | basic | Equivalent | Proto reused | 22270829
R3 | 10k | Resistor_SMD:R_0402_1005Metric | RC0402JR-0710KL | C25744 | C25744 | 0402WGF1002TCE | 0402 | basic | Equivalent | Proto reused | 22270829
R4 | 1k | Resistor_SMD:R_0402_1005Metric | RC0402FR-071KL | C11702 | C11702 | 0402WGF1001TCE | 0402 | basic | Equivalent | Proto reused | 8054795
R5 | 10 | Resistor_SMD:R_0402_1005Metric | RC0402FR-0710RL | C25077 | C25077 | 0402WGF100JTCE | 0402 | basic | Equivalent | Proto reused | 1816401
R6 | 1 | Resistor_SMD:R_0805_2012Metric | ESR10EZPJ1R0 | C253344 | C253344 | ESR10EZPJ1R0 | 0805 | extended | Exact MPN | Proto reused | 3692
R7 | 49.9 | Resistor_SMD:R_0402_1005Metric | RC0402FR-0749R9L | C25120 | C25120 | 0402WGF499JTCE | 0402 | basic | Equivalent | Proto reused | 1433950
R8 | 49.9 | Resistor_SMD:R_0402_1005Metric | RC0402FR-0749R9L | C25120 | C25120 | 0402WGF499JTCE | 0402 | basic | Equivalent | Proto reused | 1433950
R9 | 10k | Resistor_SMD:R_0402_1005Metric | RC0402JR-0710KL | C25744 | C25744 | 0402WGF1002TCE | 0402 | basic | Equivalent | Proto reused | 22270829
R14 | 10k | Resistor_SMD:R_0402_1005Metric | RC0402FR-0710KL | C25744 | C25744 | 0402WGF1002TCE | 0402 | basic | Equivalent | Bonanza existing | 22270829
R15 | 15k | Resistor_SMD:R_0402_1005Metric | 0402WGF1502TCE | C25756 | C25756 | 0402WGF1502TCE | 0402 | basic | Exact MPN | Bonanza existing | 1180843
R16 | 49.9k | Resistor_SMD:R_0402_1005Metric | RC0402FR-0749K9L | C25897 | C25897 | 0402WGF4992TCE | 0402 | preferred | Equivalent | New catalog match | 39286
R17 | 1k | Resistor_SMD:R_0402_1005Metric | RC0402FR-071KL | C11702 | C11702 | 0402WGF1001TCE | 0402 | basic | Equivalent | Proto reused | 8054795
R18 | 4.7k | Resistor_SMD:R_0402_1005Metric | RC0402FR-074K7L | C25900 | C25900 | 0402WGF4701TCE | 0402 | basic | Equivalent | Proto reused | 15689945
R19 | 4.7k | Resistor_SMD:R_0402_1005Metric | RC0402FR-074K7L | C25900 | C25900 | 0402WGF4701TCE | 0402 | basic | Equivalent | Proto reused | 15689945
R20 | 4.7k | Resistor_SMD:R_0402_1005Metric | RC0402FR-074K7L | C25900 | C25900 | 0402WGF4701TCE | 0402 | basic | Equivalent | Proto reused | 15689945
R21 | 4.7k | Resistor_SMD:R_0402_1005Metric | RC0402FR-074K7L | C25900 | C25900 | 0402WGF4701TCE | 0402 | basic | Equivalent | Proto reused | 15689945
R22 | 10k | Resistor_SMD:R_0402_1005Metric | RC0402JR-0710KL | C25744 | C25744 | 0402WGF1002TCE | 0402 | basic | Equivalent | Proto reused | 22270829
R23 | 5.1k | Resistor_SMD:R_0402_1005Metric | RMCF0402JT5K10 | C25905 | C25905 | 0402WGF5101TCE | 0402 | basic | Equivalent | Bonanza existing | 6254649
R24 | 5.1k | Resistor_SMD:R_0402_1005Metric | RMCF0402JT5K10 | C25905 | C25905 | 0402WGF5101TCE | 0402 | basic | Equivalent | Bonanza existing | 6254649
R25 | 10k | Resistor_SMD:R_0402_1005Metric | 0402WGF1002TCE | C25744 | C25744 | 0402WGF1002TCE | 0402 | basic | Exact MPN | Bonanza existing | 22270829
R26 | 20k | Resistor_SMD:R_0402_1005Metric | RC0402FR-0720KL | C25765 | C25765 | 0402WGF2002TCE | 0402 | basic | Equivalent | New catalog match | 3196949
R27 | 47k | Resistor_SMD:R_0402_1005Metric | 0402WGF4702TCE | C25792 | C25792 | 0402WGF4702TCE | 0402 | basic | Exact MPN | Bonanza existing | 5617960
R28 | 15k | Resistor_SMD:R_0402_1005Metric | 0402WGF1502TCE | C25756 | C25756 | 0402WGF1502TCE | 0402 | basic | Exact MPN | Bonanza existing | 1180843
R29 | 27k | Resistor_SMD:R_0402_1005Metric | 0402WGF2702TCE | C25771 | C25771 | 0402WGF2702TCE | 0402 | preferred | Exact MPN | Bonanza existing | 316873
R30 | 5.1k | Resistor_SMD:R_0402_1005Metric | 0402WGF5101TCE | C25905 | C25905 | 0402WGF5101TCE | 0402 | basic | Exact MPN | Bonanza existing | 6254649
R31 | 5.1k | Resistor_SMD:R_0402_1005Metric | 0402WGF5101TCE | C25905 | C25905 | 0402WGF5101TCE | 0402 | basic | Exact MPN | Bonanza existing | 6254649
R32 | 5.1k | Resistor_SMD:R_0402_1005Metric | 0402WGF5101TCE | C25905 | C25905 | 0402WGF5101TCE | 0402 | basic | Exact MPN | Bonanza existing | 6254649
R33 | 5.6k | Resistor_SMD:R_0402_1005Metric | RC0402FR-075K6L | C25908 | C25908 | 0402WGF5601TCE | 0402 | preferred | Equivalent | Proto reused | 197495
R34 | 10k | Resistor_SMD:R_0402_1005Metric | RC0402JR-0710KL | C25744 | C25744 | 0402WGF1002TCE | 0402 | basic | Equivalent | Proto reused | 22270829
R35 | 1k | Resistor_SMD:R_0402_1005Metric | RC0402FR-071KL | C11702 | C11702 | 0402WGF1001TCE | 0402 | basic | Equivalent | Proto reused | 8054795
R36 | 1k | Resistor_SMD:R_0402_1005Metric | RC0402FR-071KL | C11702 | C11702 | 0402WGF1001TCE | 0402 | basic | Equivalent | Proto reused | 8054795
R37 | 1k | Resistor_SMD:R_0402_1005Metric | RC0402FR-071KL | C11702 | C11702 | 0402WGF1001TCE | 0402 | basic | Equivalent | Proto reused | 8054795
R38 | 1k | Resistor_SMD:R_0402_1005Metric | RC0402FR-071KL | C11702 | C11702 | 0402WGF1001TCE | 0402 | basic | Equivalent | Proto reused | 8054795
R39 | 1k | Resistor_SMD:R_0402_1005Metric | RC0402FR-071KL | C11702 | C11702 | 0402WGF1001TCE | 0402 | basic | Equivalent | Proto reused | 8054795
R40 | 1k | Resistor_SMD:R_0402_1005Metric | RC0402FR-071KL | C11702 | C11702 | 0402WGF1001TCE | 0402 | basic | Equivalent | Proto reused | 8054795
R41 | 1k | Resistor_SMD:R_0402_1005Metric | RC0402FR-071KL | C11702 | C11702 | 0402WGF1001TCE | 0402 | basic | Equivalent | Proto reused | 8054795
R42 | 1k | Resistor_SMD:R_0402_1005Metric | RC0402FR-071KL | C11702 | C11702 | 0402WGF1001TCE | 0402 | basic | Equivalent | Proto reused | 8054795
R43 | 1k | Resistor_SMD:R_0402_1005Metric | RC0402FR-071KL | C11702 | C11702 | 0402WGF1001TCE | 0402 | basic | Equivalent | Proto reused | 8054795
R44 | 1k | Resistor_SMD:R_0402_1005Metric | RC0402FR-071KL | C11702 | C11702 | 0402WGF1001TCE | 0402 | basic | Equivalent | Proto reused | 8054795
R45 | 1k | Resistor_SMD:R_0402_1005Metric | RC0402FR-071KL | C11702 | C11702 | 0402WGF1001TCE | 0402 | basic | Equivalent | Proto reused | 8054795
R46 | 1k | Resistor_SMD:R_0402_1005Metric | RC0402FR-071KL | C11702 | C11702 | 0402WGF1001TCE | 0402 | basic | Equivalent | Proto reused | 8054795
R47 | 1k | Resistor_SMD:R_0402_1005Metric | RC0402FR-071KL | C11702 | C11702 | 0402WGF1001TCE | 0402 | basic | Equivalent | Proto reused | 8054795
R48 | 1k | Resistor_SMD:R_0402_1005Metric | RC0402FR-071KL | C11702 | C11702 | 0402WGF1001TCE | 0402 | basic | Equivalent | Proto reused | 8054795
R49 | 1k | Resistor_SMD:R_0402_1005Metric | RC0402FR-071KL | C11702 | C11702 | 0402WGF1001TCE | 0402 | basic | Equivalent | Proto reused | 8054795
R50 | 1k | Resistor_SMD:R_0402_1005Metric | RC0402FR-071KL | C11702 | C11702 | 0402WGF1001TCE | 0402 | basic | Equivalent | Proto reused | 8054795
R51 | 1k | Resistor_SMD:R_0402_1005Metric | RC0402FR-071KL | C11702 | C11702 | 0402WGF1001TCE | 0402 | basic | Equivalent | Proto reused | 8054795
R52 | 1k | Resistor_SMD:R_0402_1005Metric | RC0402FR-071KL | C11702 | C11702 | 0402WGF1001TCE | 0402 | basic | Equivalent | Proto reused | 8054795
R53 | 5.1k | Resistor_SMD:R_0402_1005Metric | 0402WGF5101TCE | C25905 | C25905 | 0402WGF5101TCE | 0402 | basic | Exact MPN | Bonanza existing | 6254649
SW3 | SWITCH-SPST | bitaxe:SW-SMD_TC-S3601-3.5-260G-F0.6 | TC-S3601-3.5-260G-F0.6 | C49101620 | C49101620 | TC-S3601-3.5-260G-F0.6 | SMD | extended | Exact MPN | Bonanza existing | 128146
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

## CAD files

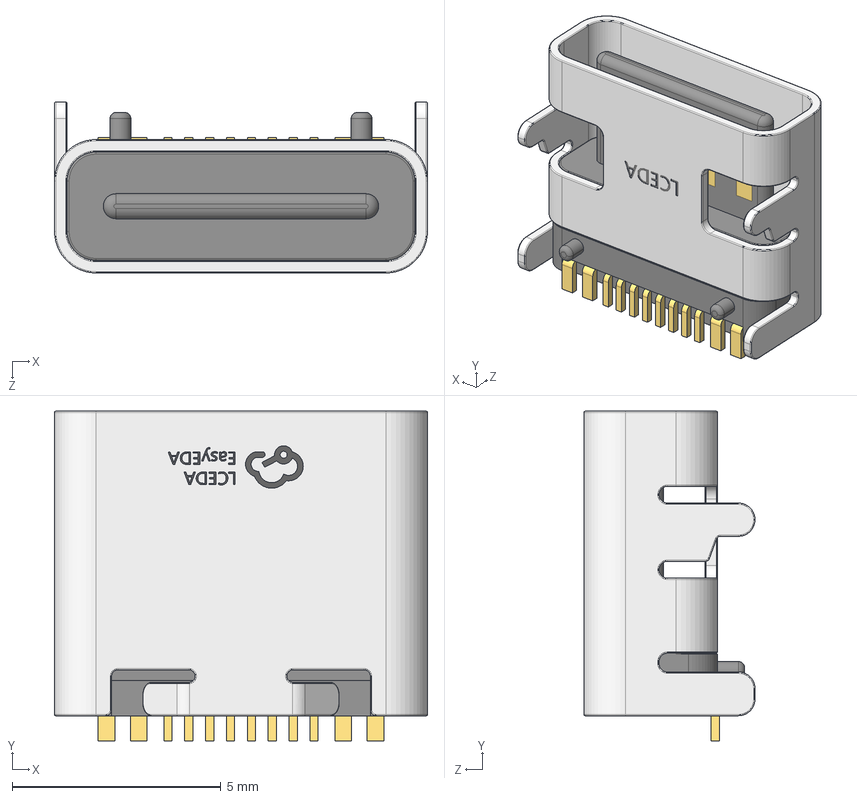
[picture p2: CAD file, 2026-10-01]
3d/USB-C_SMD-TYPE-C-31-M-12_1.step
8.94 x 7.90 x 4.10 mm

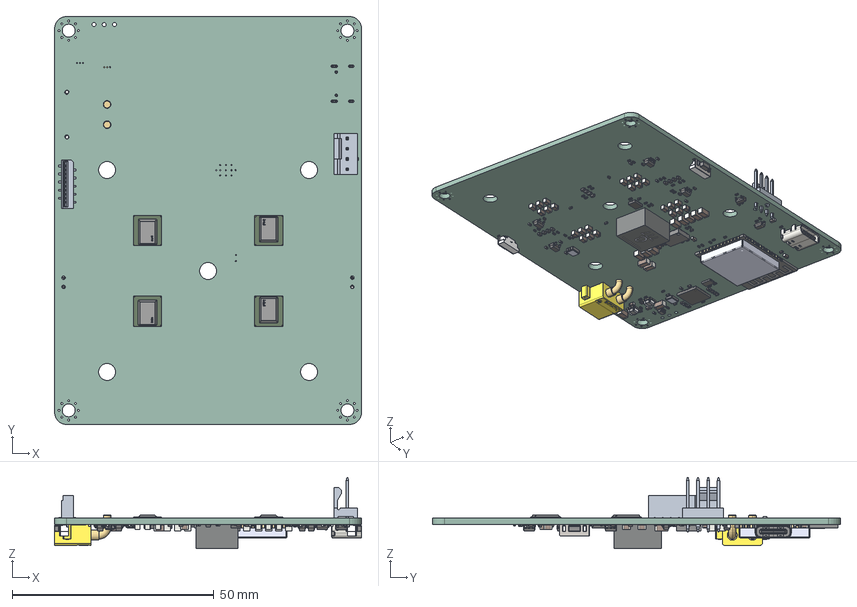
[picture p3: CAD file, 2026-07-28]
bitaxeBonanza-1002x.step
76.1 x 101.0 x 17.6 mm
substrate_part x 4
die_part x 4
underfill_part x 4
intelLogo_part x 4
pin1_part x 4
square_part x 4
plus_part x 4
bracket_part x 4
pads_part x 4
C-1-1735042-0
C_0805_2012Metric x 25
C_0402_1005Metric x 44
C_1206_3216Metric x 12
R_0402_1005Metric x 43
D_SOD_523 x 12
C_0603_1608Metric x 6
SOLDERMASK-SIP x 2
METAL-SIL0008D x 2
SUBSTRATE-SIP x 2
INDUCTOR-BODY-MLV x 2
INDUCTOR-TERMNL-MLV x 4
SOT-23-5 x 4
QFN-56-1EP_7x7mm_P0.4mm_EP3.2x3.2mm
XT30PW-M
Coilcraft-XAL1060
USB_C_Receptacle_16P_TopMnt_Horizontal_GCT_USB4105-xx-A
ECS-80-8-33-JGN-TR3
BODY-SOT
LEAD-SOT x 6
PIN1-ID
RVF40
SOT-23
R_0805_2012Metric
ECS-3225MVQ-160-CN-TR
SW-SMD_TC-S3601-3.5-260G-F0.6 x 2
D_SOD-123
ESP32-S3-WROOM-1-N8R2
bitaxeBonanza-unsaved-export-V78T2N_PCB

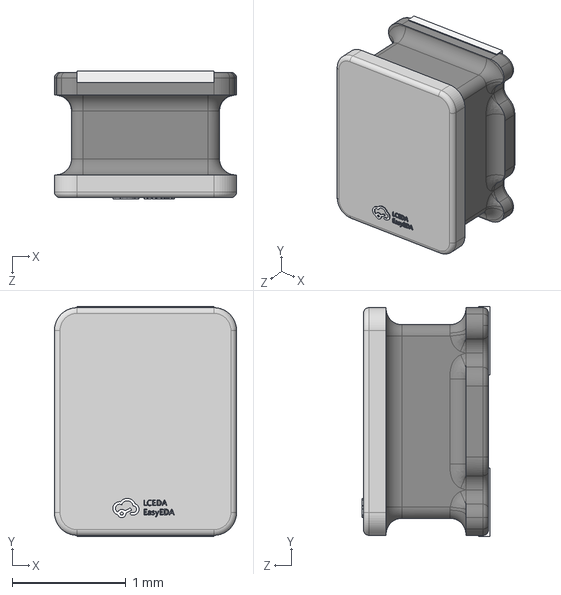
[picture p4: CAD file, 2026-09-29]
3d/IND-SMD_L2.0-W1.6-H1.1.step
1.60 x 2.02 x 1.12 mm

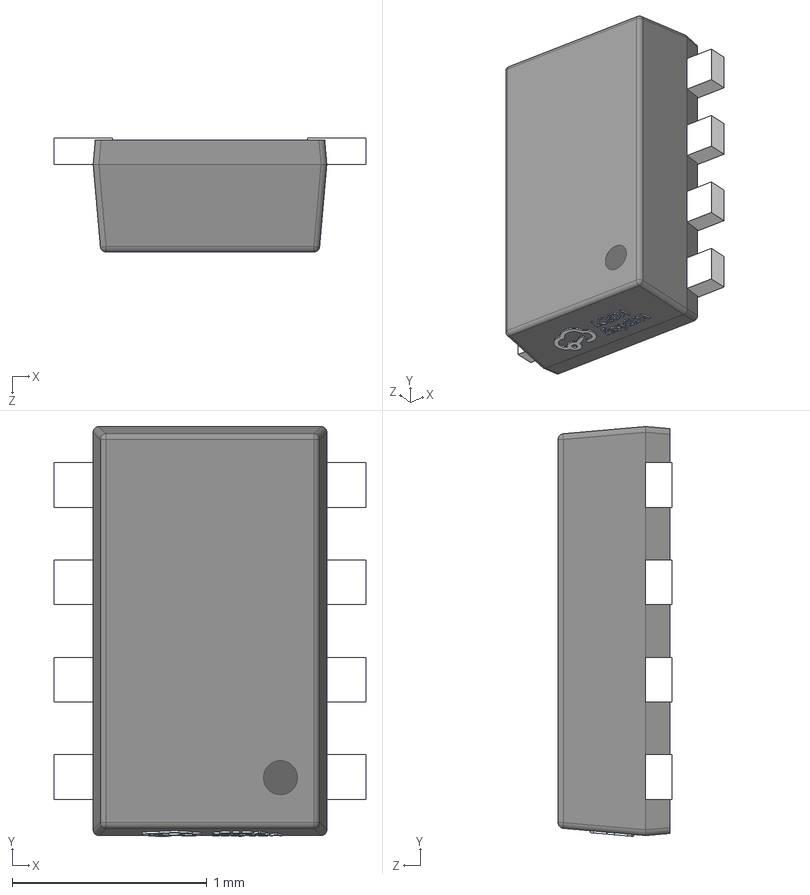
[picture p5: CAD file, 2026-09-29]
3d/SOT-583-8_L2.1-W1.2-P0.50-LS1.6-BR.step
1.60 x 2.10 x 0.585 mm

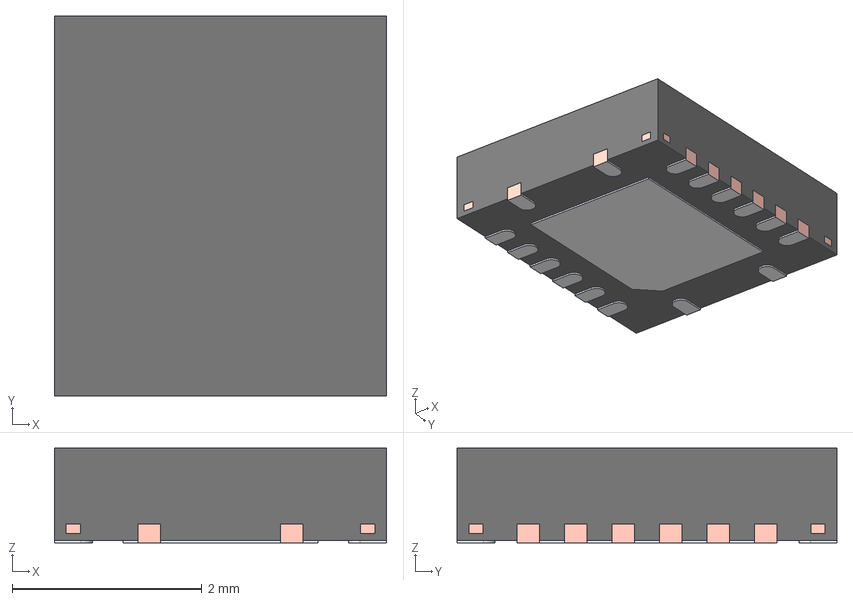
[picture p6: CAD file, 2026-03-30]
3d/RGY0016A.stp
3.50 x 4.00 x 1.00 mm
FRAME
PIN1_AREA

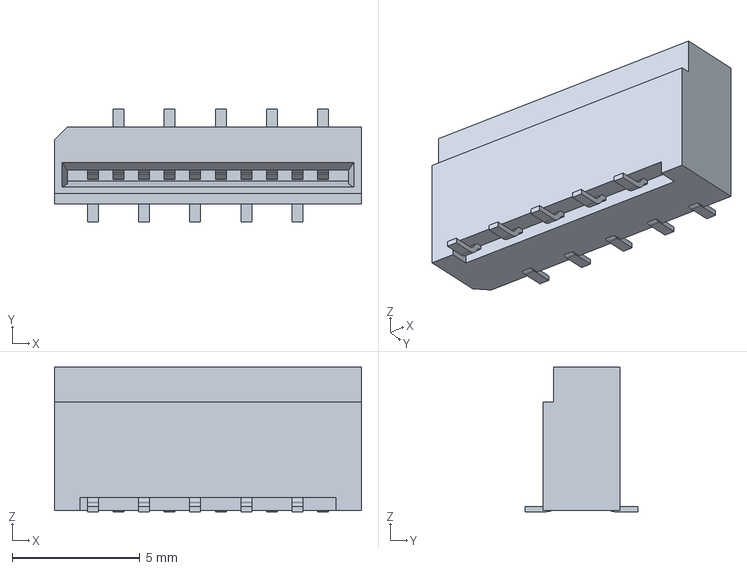
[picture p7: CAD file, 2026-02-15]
3d/c-1-1735042-0-m-3d.stp
12.0 x 4.40 x 5.65 mm

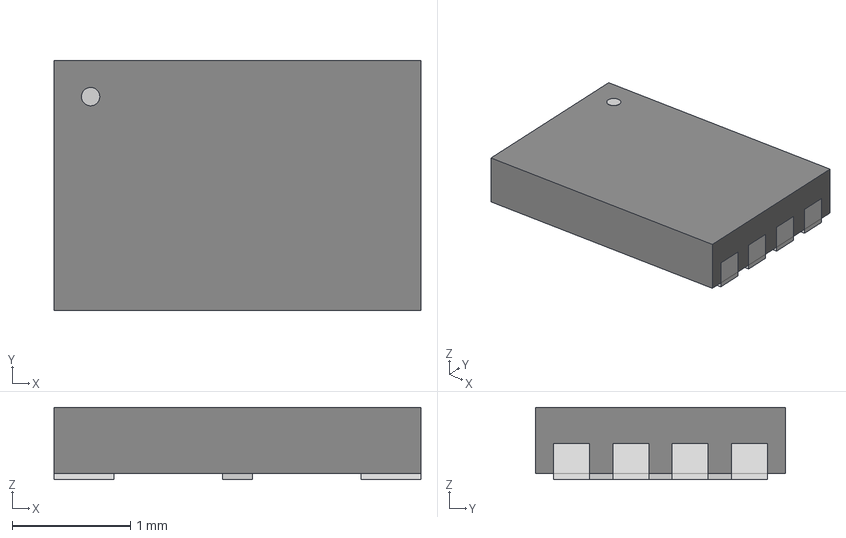
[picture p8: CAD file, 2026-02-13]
3d/USON-8_UX_2x3x0p6_WIN.step
3.10 x 2.11 x 0.612 mm

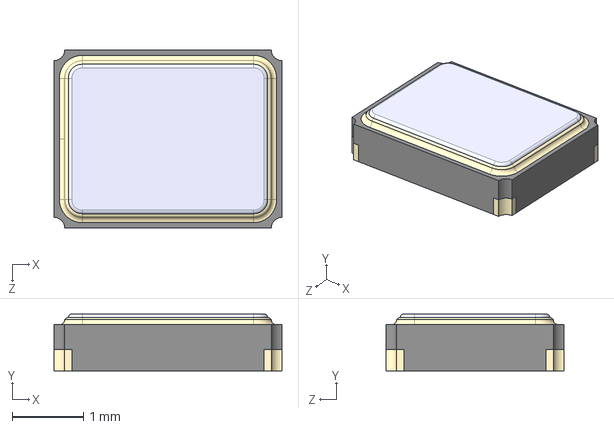
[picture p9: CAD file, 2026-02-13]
3d/Crystal_3225.step
3.20 x 0.8 x 2.50 mm

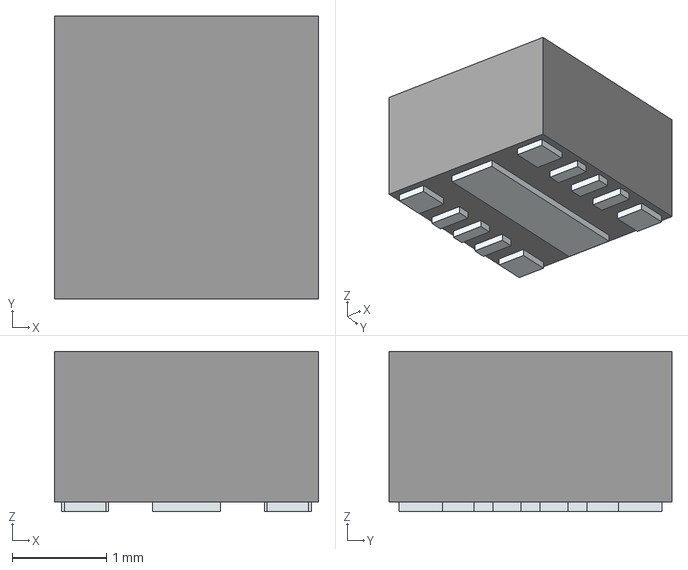
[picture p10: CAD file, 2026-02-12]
3d/TPSM82903SISR.stp
2.80 x 3.00 x 1.70 mm
Pins

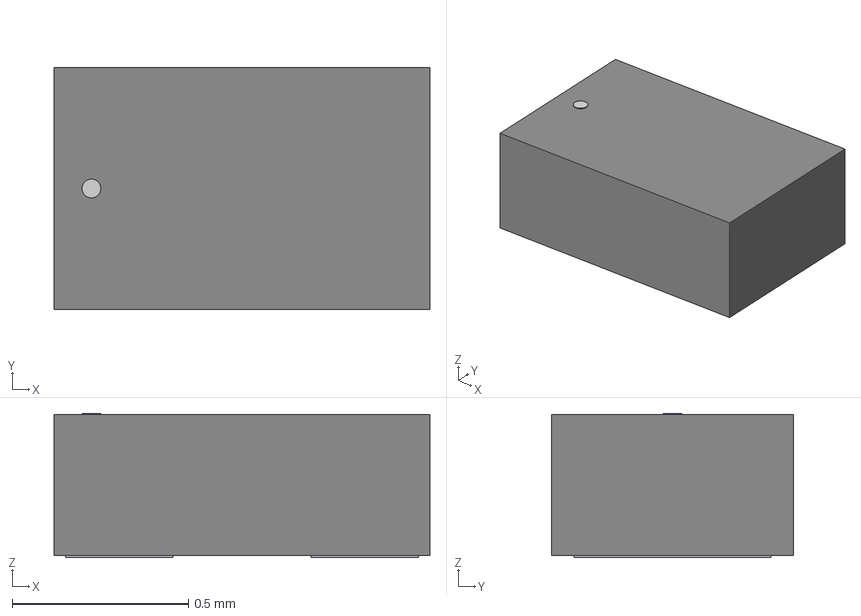
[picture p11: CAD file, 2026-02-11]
3d/DIODE_DLLFSD01LPH4-7B_DIO.step
1.07 x 0.686 x 0.409 mm

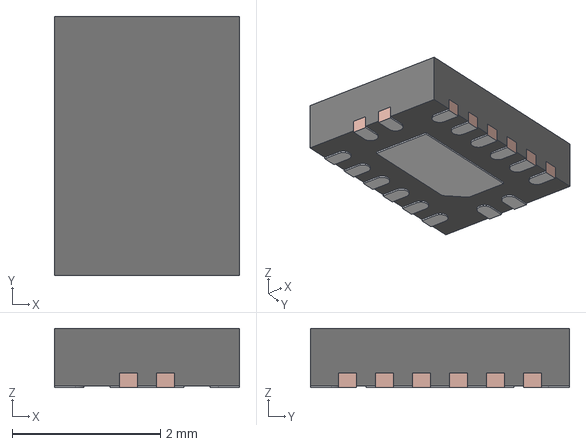
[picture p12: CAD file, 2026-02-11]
3d/BQB0016A.stp
2.50 x 3.50 x 0.8 mm
FRAME

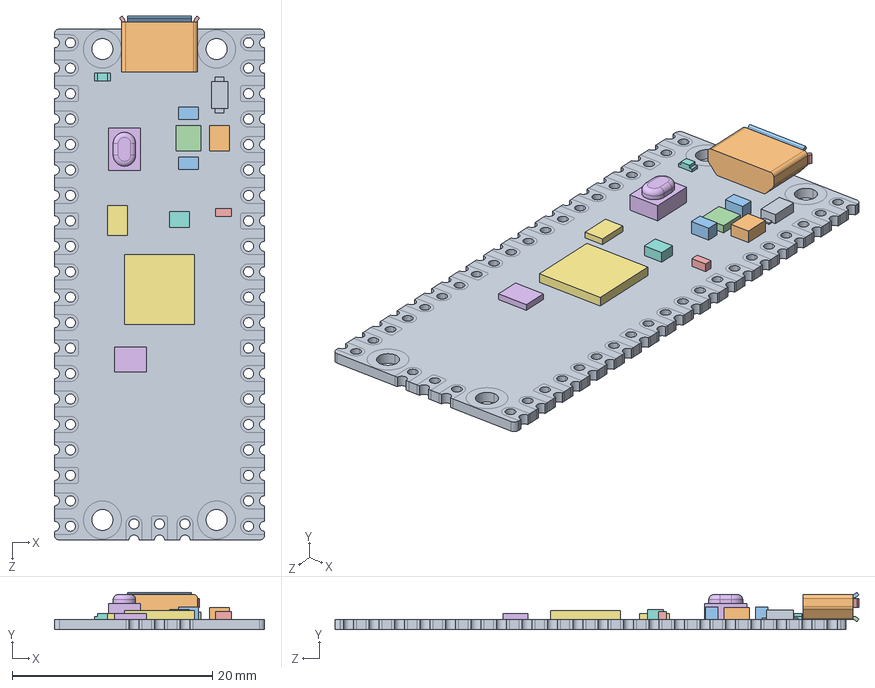
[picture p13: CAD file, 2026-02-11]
3d/RP-006426-DD-A-Raspberry Pi Pico 2 3D CAD Model R5 24 07 24.step
21.0 x 3.73 x 52.3 mm
PICO_REF_BOARD
PICO_REF_USB
PICO_REF_SWITCH
PICO_REF_MICROCONTROLLER
PICO_REF_LED
PICO_REF_COMP_1
PICO_REF_COMP_2
PICO_REF_COMP_3 x 2
PICO_REF_COMP_4
PICO_REF_COMP_5
PICO_REF_COMP_6
PICO_REF_COMP_7
PICO_REF_INDUCTOR

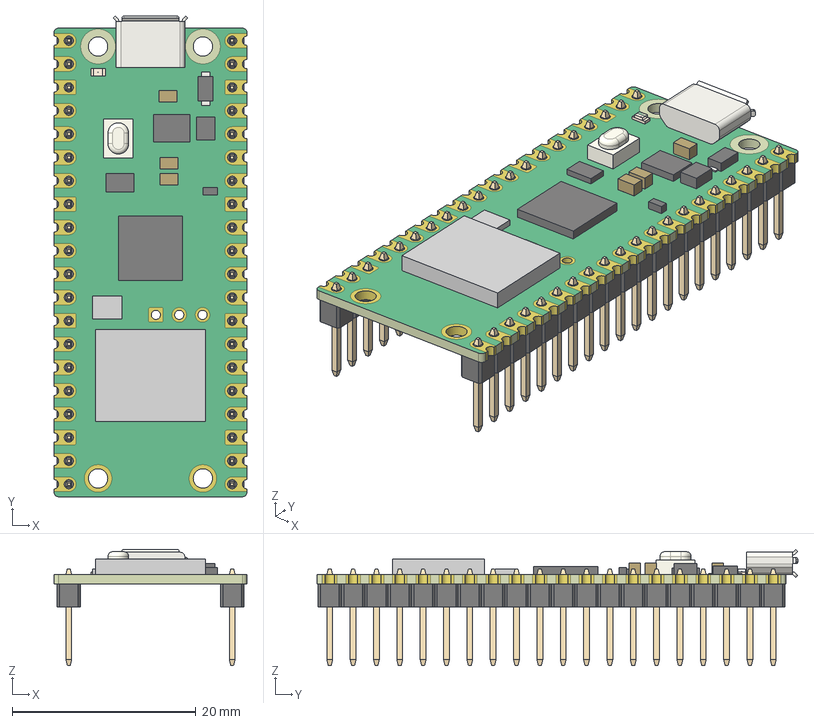
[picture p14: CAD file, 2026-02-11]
3d/RaspberryPi_Pico_W_AddedHeaders.step
21.0 x 52.3 x 12.6 mm

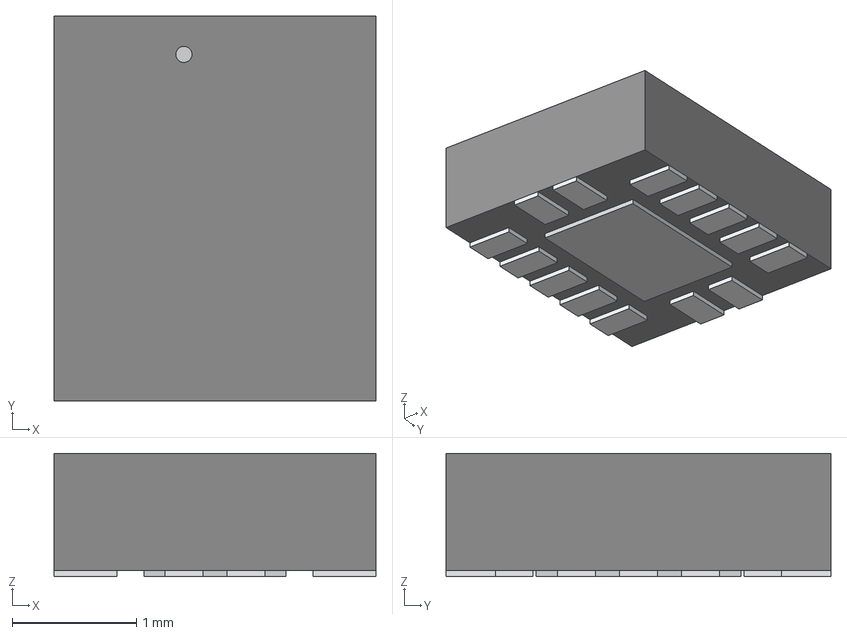
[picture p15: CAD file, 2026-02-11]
3d/DHVQFN14_SOT762-1_NEX.step
2.59 x 3.10 x 0.993 mm

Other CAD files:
3d/BZM2.step
3d/IND_-1R5MC_SUM.step
3d/Coilcraft-XAL1060.STEP
3d/TSM-104-01-L-SH-A.stp
3d/141_TL3330AFxxxQG.stp
3d/21-0164B_L622-1_MXM.step
3d/2R5TPE220MAFB.step
3d/470531000.stp
3d/54-00164.STEP
3d/BM04B-SRSS-TB.STEP
3d/BM1368xx.stp
3d/BZM2model.step
3d/BitaxeGT_heatsink.step
3d/Bitaxe_Heatsink.step
3d/CS1213AG-tr.stp
3d/CUI_DEVICES_PJ-002AH.step
3d/CUI_DEVICES_PJ-036AH-SMT-TR.step
3d/CUI_DEVICES_PJ-037AH.step
3d/CX3225SB16000H0FLJCC.STEP
3d/Coilcraft-SLC1175.STEP
3d/Cree_PLCC6.stp
3d/DCK0006A.stp
3d/DISST7789-176x320.STEP
3d/DQG0008A.stp
3d/DQH0008A.stp
3d/DQN0004A.stp
3d/DRC0010J.stp
3d/DRL0006A.stp
3d/ECS-3225MV-500-CN-TR.STEP
3d/ESP32-S3-WROOM-1-N8R2--3DModel-STEP-56544.STEP
3d/FFC2B35-08-T.STEP
3d/FP1006V2-R.STEP
3d/FPC-SMD_P0.50-8P_FGS-XJ-H2.0.step
3d/FTSH-105-01-F-DV-K.stp
3d/Fan 60x60x25mm.stp
3d/GT heatsink.step
3d/IHLP2020CZ.step
3d/OLED_0.91_128x32.stp
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

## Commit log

2023-11-16 initial import
    [UFQFPN-48_7X7X0P55MM.step, asic.kicad_sch, blockaxe1.kicad_pcb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]
2023-11-20 adding logo and docs
    [asic.kicad_sch, blockaxe1.kicad_pcb, blockaxe1.kicad_sch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]
2023-12-01 added BZM2 footprint
    [asic.kicad_sch, blockaxe1.kicad_sch, stm32.kicad_sch]
2023-12-02 migrated over lots of bitaxe parts to blockaxe
    [ECS-3225MV-500-CN-TR.STEP, asic.kicad_sch, blockaxe1.kicad_pcb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]
2023-12-10 switched to the LM27402 buck regulator
    [DQG0008A.stp, RUM0016A.stp, power.kicad_sch]
2023-12-10 all the footprints are in?
    [CSD17312Q5.step, asic.kicad_sch, blockaxe1.kicad_pcb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]
2023-12-11 routed the buck reg. started placing board
    [blockaxe1.kicad_pcb, power.kicad_sch]
2023-12-13 more placing and routing
    [470531000.stp, 54-00164.STEP, CS1213AG-tr.stp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]
2023-12-16 more routing. switched to RA buttons, moved the buck closer to the barrel
    [EVQ-9P701P.stp, TXB0104RGYR.STEP, blockaxe1.kicad_pcb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]
2023-12-20 finished routing. switched back to THT barrel
    [CUI_DEVICES_PJ-002B.step, TSOT-23-5_RIT.step, asic.kicad_sch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]
2023-12-21 added gerbers and BOM
    [asic.kicad_sch, blockaxe1 BOM.xlsx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]
2024-02-21 Switching to 1.2V Oscillator for #3 Switch the level shifter for #4
    [asic.kicad_sch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]
2024-02-21 added test points for #7
    [stm32.kicad_sch]
2024-02-21 changed buttons for #5 flipped display for #2
    [TL3330AF260QG.step, asic.kicad_sch, blockaxe1.kicad_pcb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]
2024-02-22 switched barrel plug for #8. touched up schematic, DRC, generated BOM, generated Gerbers
    [EJ503A.step, asic.kicad_sch, blockaxe1 BOM.xlsx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]
2024-02-22 added stm32 crystal for #9
    [ECS-80-12-33-JGN-TR.step, blockaxe1 BOM.xlsx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]
2024-02-22 generated gerbers, updated BOM C18 error
    [blockaxe1 BOM.xlsx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]
2024-03-15 update to KiCad8, DNP 32kHz crystal
    [asic.kicad_sch, blockaxe1.kicad_pcb, blockaxe1.kicad_sch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]
2025-03-25 switch to bitaxeAura/GT base
    [21-0164B_L622-1_MXM.step, 2R5TPE220MAFB.step, 470531000.stp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]
2025-03-25 pulled in the BZM2 symbol and footprint
    [BitaxeBonanza.kicad_sch, asic.kicad_sch]
2025-05-22 added 8 ASICs in schematic
    [BitaxeBonanza.kicad_pcb, BitaxeBonanza.kicad_sch, DCK0005A.stp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]
2025-06-11 moved ASIC bypass caps out to separate sheet
    [BitaxeBonanza.kicad_pcb, BitaxeBonanza.kicad_sch, asic.kicad_sch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]
2025-06-12 added level shifters to schematic
    [SOD-323FL_UMD2__ROM.step, asic.kicad_sch, shifter.kicad_sch]
2025-06-13 made the board double wide. rough ASIC and vreg placement.
    [BitaxeBonanza.kicad_pcb, BitaxeBonanza.kicad_sch, asic.kicad_sch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]
2025-06-13 switch to EMC2302 for 2 fans and no temp sensor
    [BitaxeBonanza.kicad_pcb, fan.kicad_sch]
2025-06-17 ASICs placed. most other parts placed.
    [BitaxeBonanza.kicad_pcb, BitaxeBonanza.kicad_sch, asic.kicad_sch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]
2025-06-20 routing is done. Power planes look good. DRC pass
    [141_TL3330AFxxxQG.stp, BZM2model.step, BitaxeBonanza.kicad_pcb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]
2025-06-24 moved fan connectors (and controller) up to the northern PCB edge
    [BitaxeBonanza.kicad_pcb, GT heatsink.step]
2026-02-11 switch to the bitaxeBIRDS based pre-bonanza
    [BQB0016A.stp, BZM2.step, BitaxeBonanza BOM.csv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]
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2026-02-11 update pcbnew drawing sheet
    [BitaxeBonanza.kicad_pcb, BitaxeBonanza.kicad_sch, data.kicad_sch]
2026-02-12 most placement and routing done
    [BitaxeBonanza.kicad_pcb, BitaxeBonanza.kicad_sch, data.kicad_sch]
2026-02-12 add missing 3d, update render, update readme
    [BitaxeBonanza.kicad_pcb, TPS82130SILR.stp, power.kicad_sch]
2026-02-12 changed TPS82130 voltage regulators to TPSM82903. Connected ESP32<->RP2040 CTRL serial port. made top mounting holes plated.
    [BitaxeBonanza.kicad_pcb, BitaxeBonanza.kicad_sch, TPSM82903SISR.stp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]
2026-02-13 Filled out the BOM and added missing DK part numbers. thanks Claude
    [BitaxeBonanza.kicad_pcb, Crystal_3225.step, USON-8_UX_2x3x0p6_WIN.step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]
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2026-02-15 switched to SMD FFC for the display connector
    [BitaxeBonanza.kicad_pcb, BitaxeBonanza.kicad_sch, c-1-1735042-0-m-3d.stp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]
2026-02-15 switched back to TPS82130. added BOM partnumbers
    [BitaxeBonanza.kicad_pcb, BitaxeBonanza.kicad_sch, asic.kicad_sch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]
2026-02-15 fix TPS82130 symbols
    [BitaxeBonanza.kicad_pcb, power.kicad_sch]
2026-02-15 fix pinsel connection on ASIC 3
    [BitaxeBonanza.kicad_pcb, asic.kicad_sch]
2026-02-15 add missing courtyards and re-enable DRC check
    [BitaxeBonanza.kicad_pcb]
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2026-03-30 add missing cad files. bump to kicad v10
    [BitaxeBonanza.kicad_pcb, BitaxeBonanza.kicad_sch, RGY0016A.stp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]
2026-04-07 minor silkscreen fixes. changed C1, C8 to 0805
    [BitaxeBonanza.kicad_pcb, data.kicad_sch, power.kicad_sch]
2026-07-28 update old .wrl 3d models.
    [BitaxeBonanza.kicad_pcb, bitaxeBonanza-1002x.step, bitaxeBonanza.step]
2026-09-18 paste and position new edgecuts and connector positions
    [BitaxeBonanza.kicad_pcb, BitaxeBonanza.kicad_sch, asic.kicad_sch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]
2026-09-22 migrated over the 1103x accessory voltage regulators. started rough parts placement
    [BitaxeBonanza.kicad_pcb, BitaxeBonanza.kicad_sch, data.kicad_sch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]
2026-09-29 most placements and important routing done
    [BitaxeBonanza.kicad_pcb, data.kicad_sch]
2026-09-29 switched display connector to BAP pins and UART instead of I2C. Bridge is now only ASIC serial. Added ESP32 ADC connections to domain midpoints.
    [BitaxeBonanza.kicad_pcb, BitaxeBonanza.kicad_sch, IND-SMD_L2.0-W1.6-H1.1.step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]
2026-09-29 rough routing done.. DRC time
    [BitaxeBonanza.kicad_pcb]
2026-09-29 changed inductor to Bourns SRP1245A-1R2M as the coilcraft was out of stock everywhere.
    [BitaxeBonanza.kicad_pcb, BitaxeBonanza.kicad_sch, asic.kicad_sch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]
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2026-09-30 added stitching vias. added test points for ASIC signals pre-level shifter
    [BitaxeBonanza.kicad_pcb, asic.kicad_sch, data.kicad_sch]
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2026-10-01 switched 100uF ASIC domain bypass caps to cheaper 1206
    [BitaxeBonanza.kicad_pcb, BitaxeBonanza.kicad_sch, bypass.kicad_sch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]
2026-10-01 switch to in stock USB connector
    [BitaxeBonanza.kicad_pcb, USB-C_SMD-TYPE-C-31-M-12_1.step, asic.kicad_sch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]
